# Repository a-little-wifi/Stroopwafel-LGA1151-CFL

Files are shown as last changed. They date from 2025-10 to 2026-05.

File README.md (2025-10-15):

# Stroopwafel LGA1151 Intel Coffee Lake motherboard

Trying to see how far I can get with implementing a modern-ish Intel platform in KiCad using public documentation and leaked schematics.

Here's some work in progress pictures (random layout (or ATX standard successor??? 👀)):

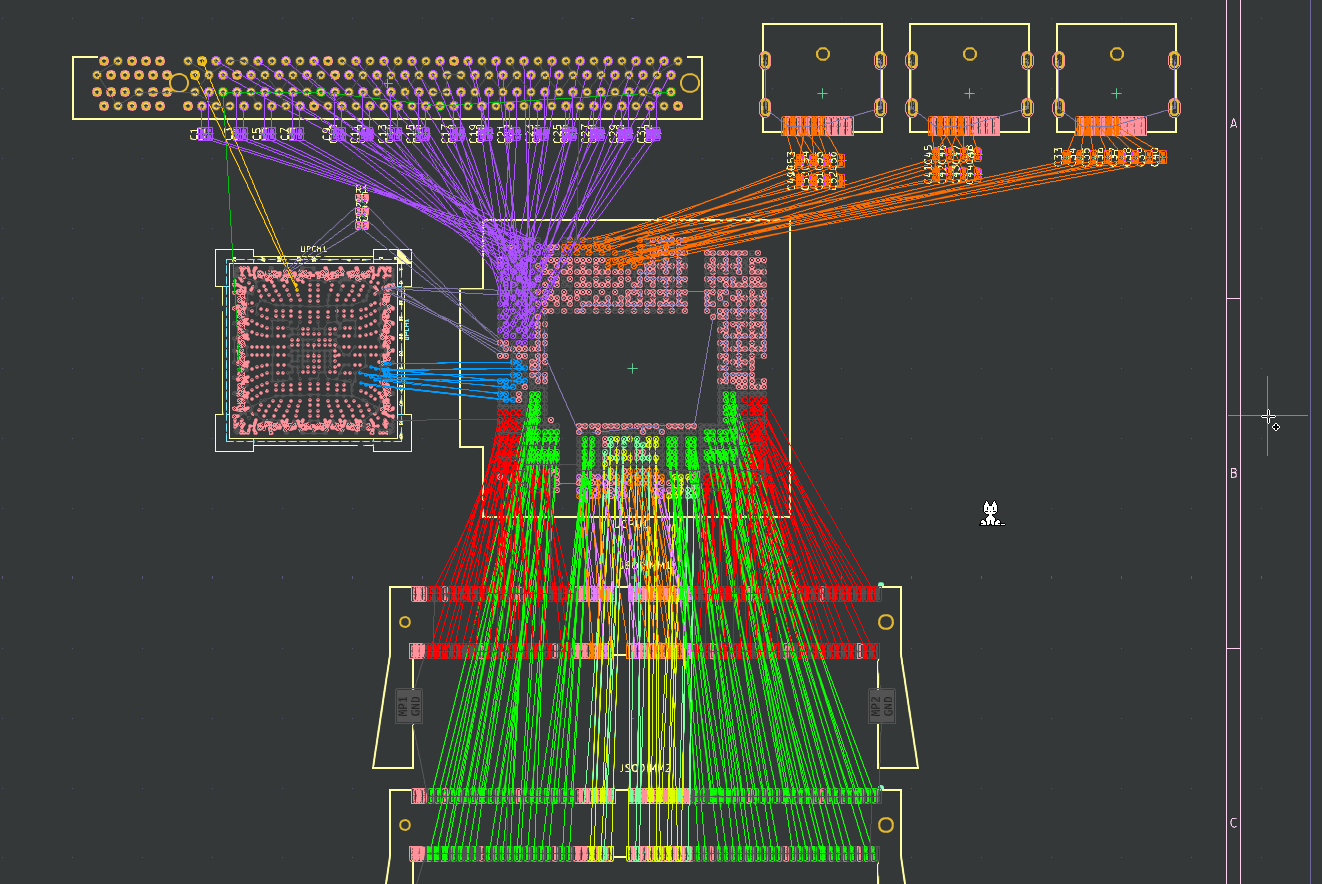
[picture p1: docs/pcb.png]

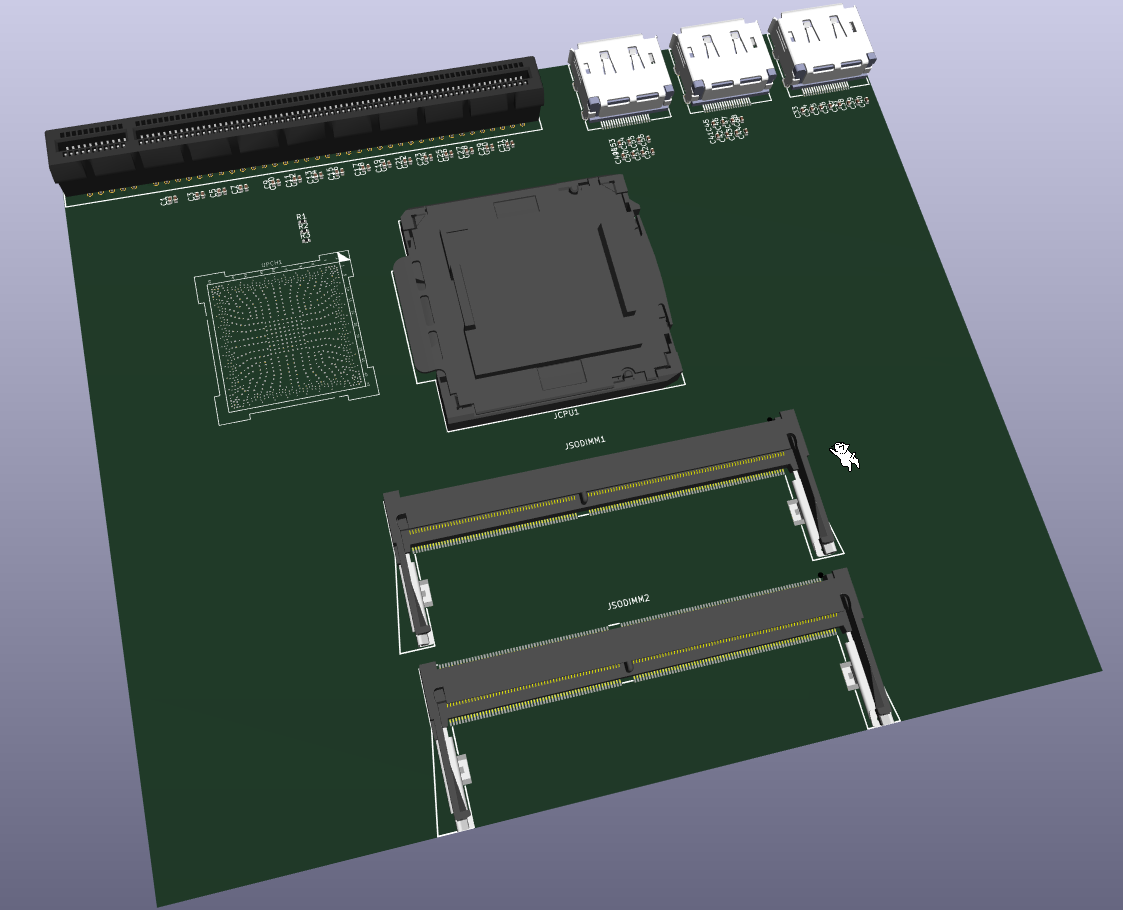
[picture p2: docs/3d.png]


Inspired by LCSC carrying LGA1151 sockets: https://www.lcsc.com/product-detail/C2761532.html (thanks for the footprint)

Thanks @mothenjoyer69 for extracting the PCH footprint from a random laptop boardview (LA-F711P)

CPU and PCH schematic symbols fully copied (and partially corrected) from pdf schematics by hand (took like 3 days...)

It's called Stroopwafel because I was eating a stroopwafel when I was trying to come up with a name. Also stroopwafels are supposed to go with coffee and it's Coffee Lake... get it?....

Mostly using LCFC NM-B551 (Lenovo Tiny5) and Wistron 17557-1 Copperbox (Acer N4660G my beloved) schematics for reference atm

The PCH footprint and symbol in this project should be applicable to (most of) Intel's 300 and 400 series chipsets. 300 series goes with 8th/9th gen and 400 series goes with 10th/11th gen.  
I'll be using a 300-series chipset for this project (probably Z390), since I'm using LGA1151. For 400 series you need LGA1200.

The goal is to create an easy to understand board and schematic layout that breaks out as much of the platform capabilities as possible.

Might build a laptop with a desktop CPU for fun later.

Am I insane? maybe. But I don't really see why I shouldn't try at the moment. It's a fun experiment at least.

No idea what board layout I'll use yet, but I don't feel like using a standard ATX formfactor, there's already plenty of boards like that. I kinda wanna make the PCH and CPU sections modular but I'll have to see about the practicalities of that.

I don't know how I'm gonna handle the EC and firmware yet, probably just gonna yoink it from an existing board and pray that it works without too much modification. I'm open to help regarding this. Maybe coreboot/libreboot?

Routing DDR4 will be fun.

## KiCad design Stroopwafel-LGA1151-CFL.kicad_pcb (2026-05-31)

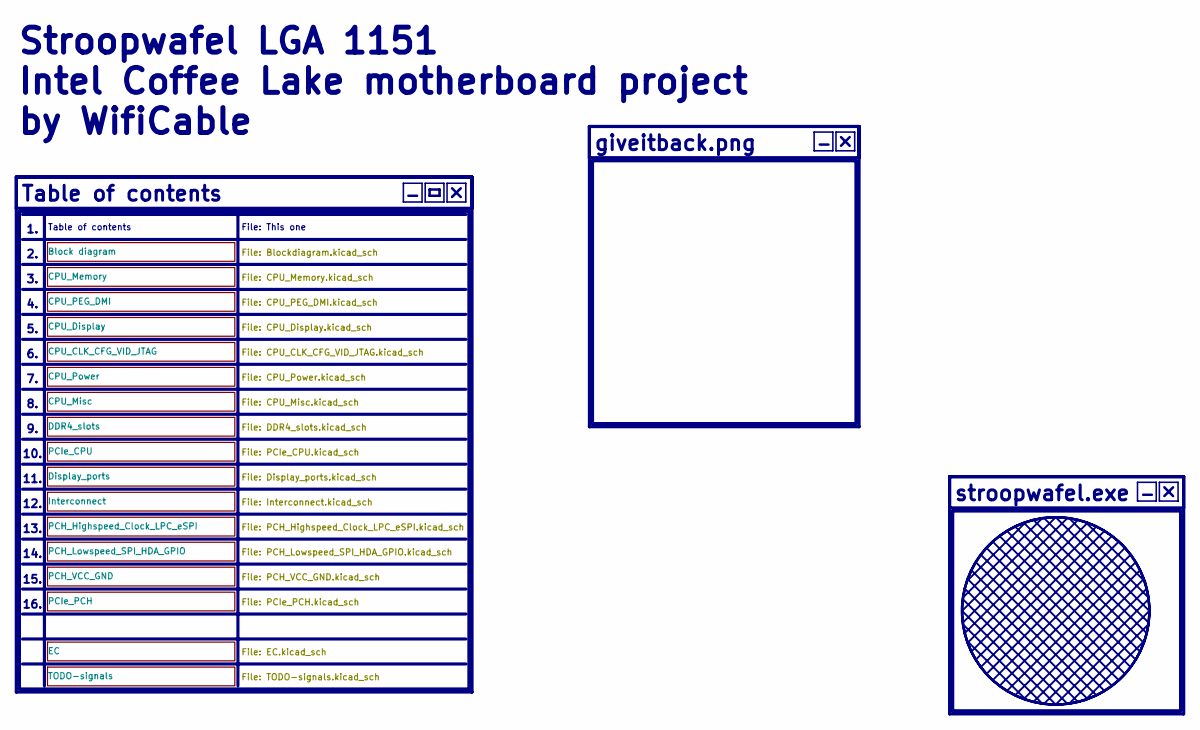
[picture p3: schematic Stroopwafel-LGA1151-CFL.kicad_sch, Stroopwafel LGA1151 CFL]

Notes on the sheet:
Stroopwafel LGA 1151 Intel Coffee Lake motherboard project by WifiCable
Table of contents
stroopwafel.exe
11.
15.
File: This one
giveitback.png
14.
16.
13.
10.
12.

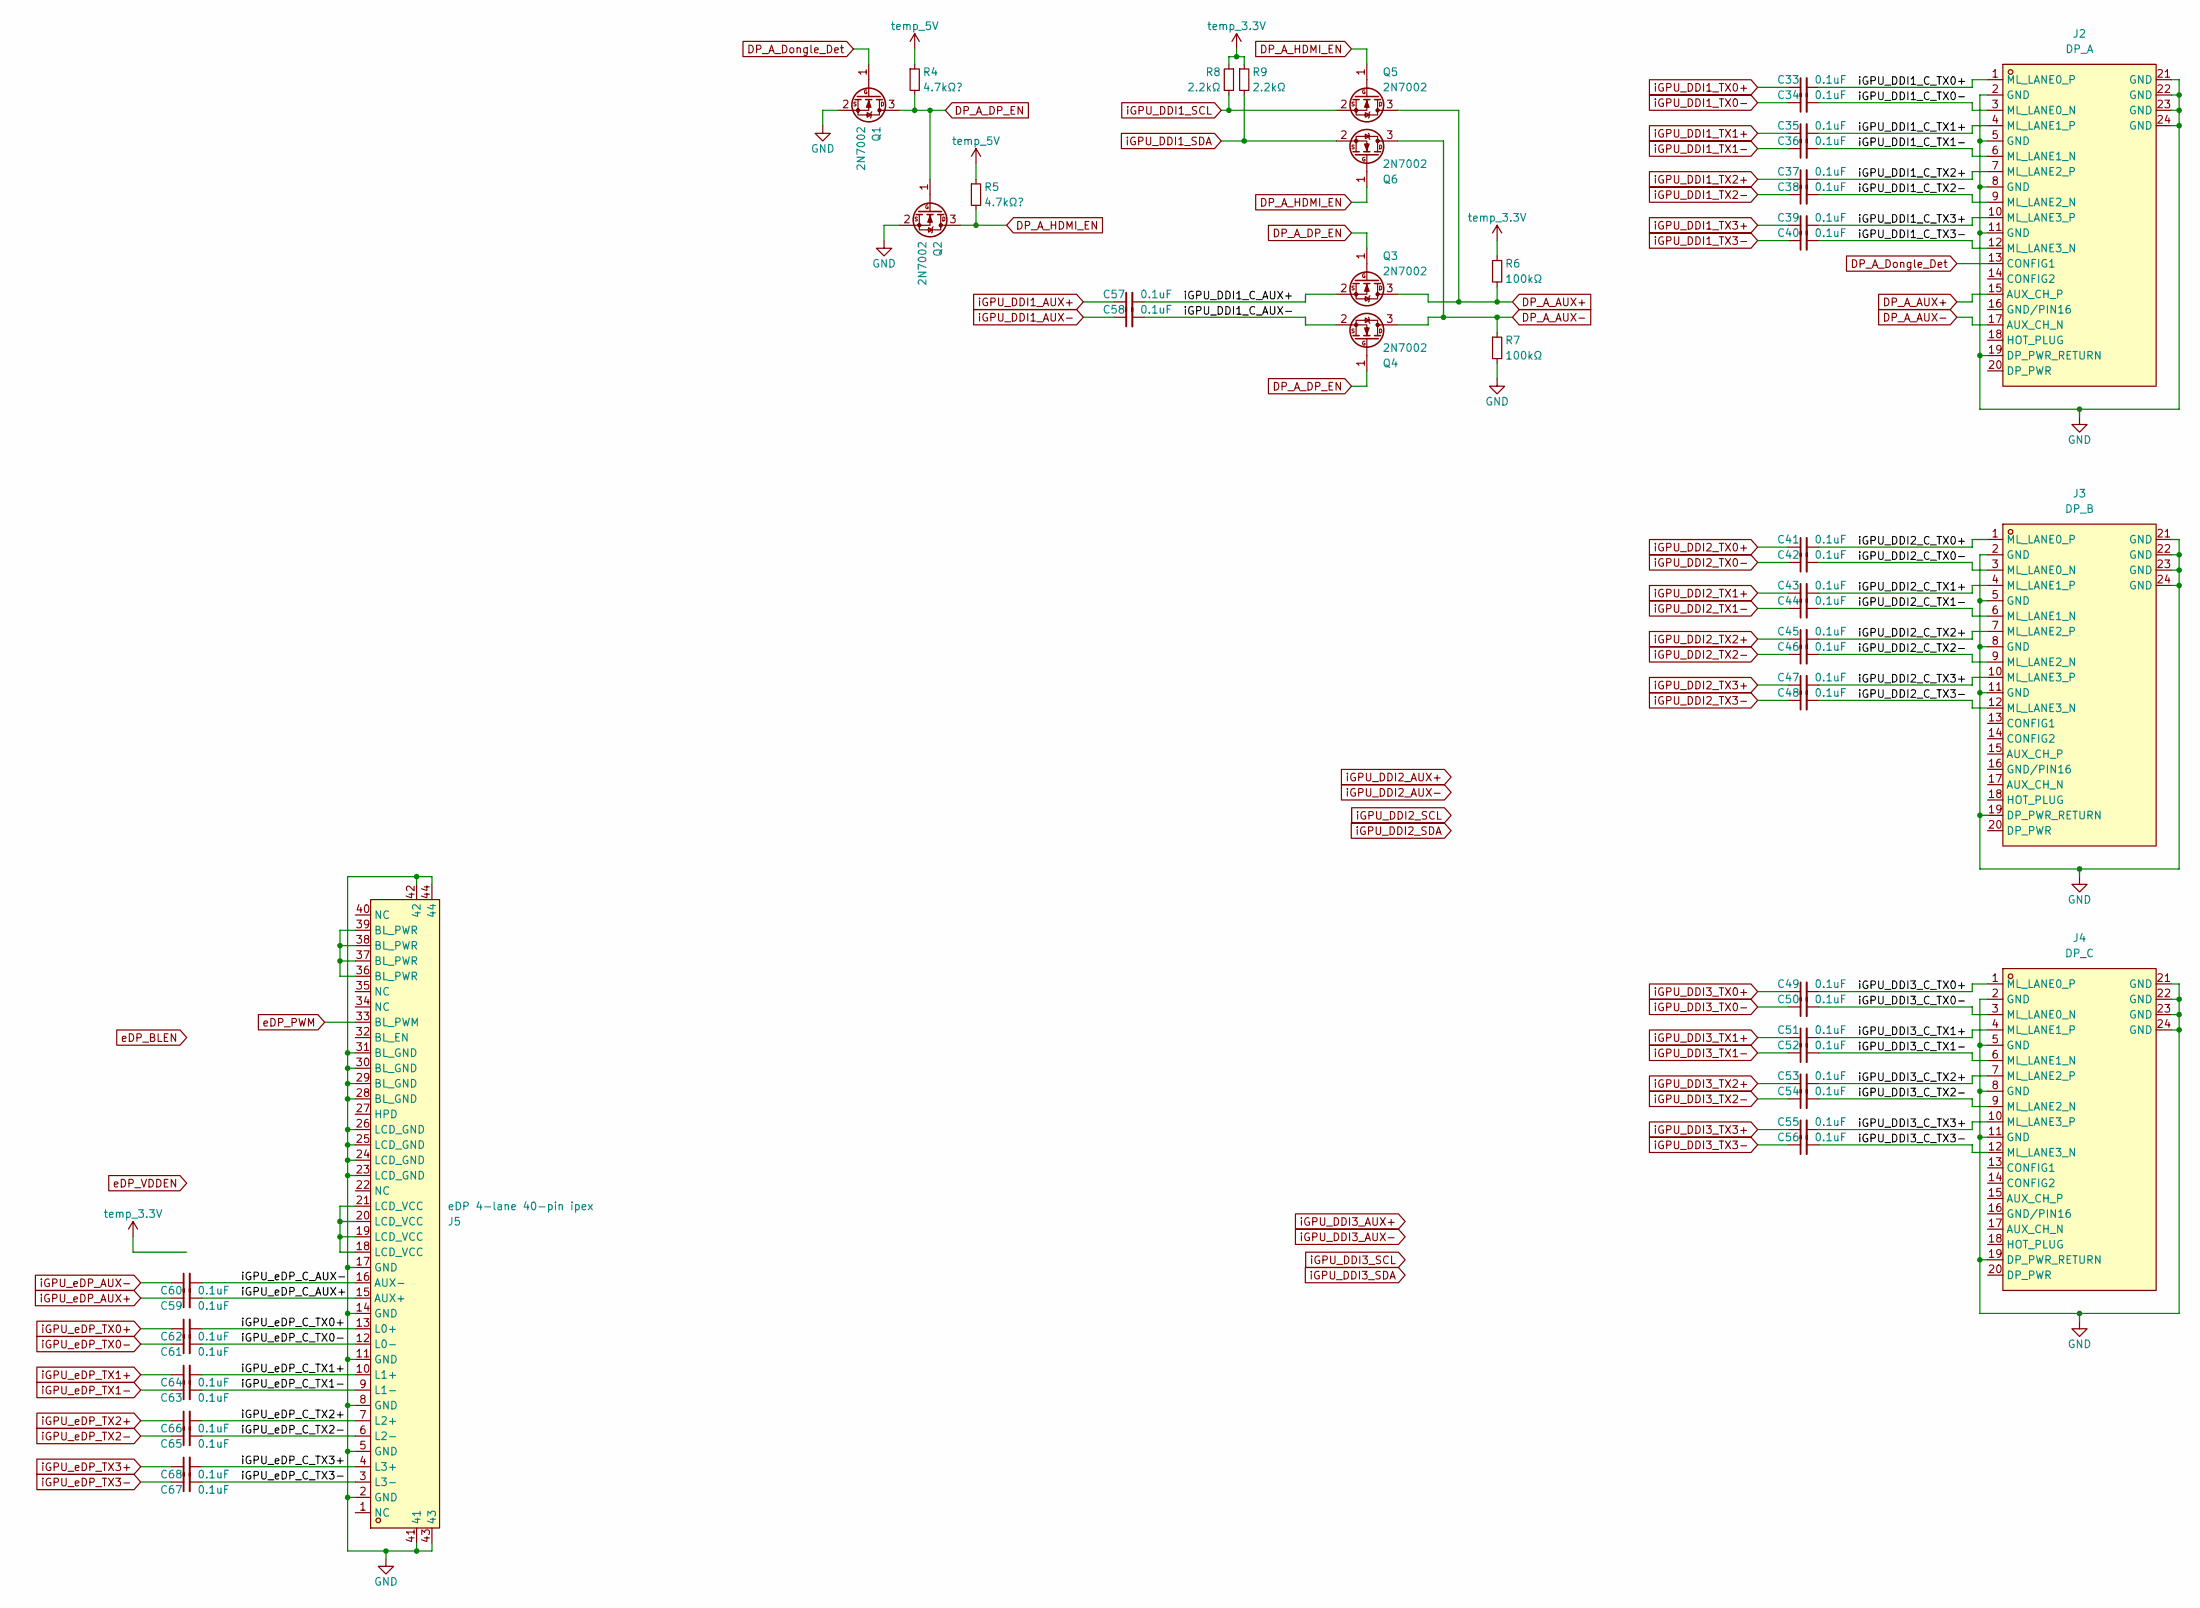
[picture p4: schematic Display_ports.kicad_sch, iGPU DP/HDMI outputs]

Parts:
C33, C34, C35, C36, C37, C38, C39, C40, C41, C42, C43, C44, C45, C46, C47, C48, C49, C50, C51, C52, C53, C54, C55, C56, C57, C58, C59, C60, C61, C62, C63, C64, C65, C66, C67, C68: 0.1uF; C_0402_1005Metric
J2: DP_A; DP-SMD_HYC16-DP20-178; LCSC Part C711350
J3: DP_B; DP-SMD_HYC16-DP20-178; LCSC Part C711350
J4: DP_C; DP-SMD_HYC16-DP20-178; LCSC Part C711350
J5: eDP 4-lane 40-pin ipex; 40pIPEX_20455-040E-76
Q1, Q2, Q3, Q4, Q5, Q6: 2N7002; SOT-23
R4, R5: 4.7kΩ?; R_0402_1005Metric
R6, R7: 100kΩ; R_0402_1005Metric
R8, R9: 2.2kΩ; R_0402_1005Metric

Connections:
/Display_ports/iGPU_DDI1_C_AUX+: C57.2, Q3.2 (S)
/Display_ports/iGPU_DDI1_C_AUX-: C58.2, Q4.2 (S)
/Display_ports/iGPU_DDI1_C_TX0+: C33.2, J2.1 (ML_LANE0_P)
/Display_ports/iGPU_DDI1_C_TX0-: C34.2, J2.3 (ML_LANE0_N)
/Display_ports/iGPU_DDI1_C_TX1+: C35.2, J2.4 (ML_LANE1_P)
/Display_ports/iGPU_DDI1_C_TX1-: C36.2, J2.6 (ML_LANE1_N)
/Display_ports/iGPU_DDI1_C_TX2+: C37.2, J2.7 (ML_LANE2_P)
/Display_ports/iGPU_DDI1_C_TX2-: C38.2, J2.9 (ML_LANE2_N)
/Display_ports/iGPU_DDI1_C_TX3+: C39.2, J2.10 (ML_LANE3_P)
/Display_ports/iGPU_DDI1_C_TX3-: C40.2, J2.12 (ML_LANE3_N)
/Display_ports/iGPU_DDI2_C_TX0+: C41.2, J3.1 (ML_LANE0_P)
/Display_ports/iGPU_DDI2_C_TX0-: C42.2, J3.3 (ML_LANE0_N)
/Display_ports/iGPU_DDI2_C_TX1+: C43.2, J3.4 (ML_LANE1_P)
/Display_ports/iGPU_DDI2_C_TX1-: C44.2, J3.6 (ML_LANE1_N)
/Display_ports/iGPU_DDI2_C_TX2+: C45.2, J3.7 (ML_LANE2_P)
/Display_ports/iGPU_DDI2_C_TX2-: C46.2, J3.9 (ML_LANE2_N)
/Display_ports/iGPU_DDI2_C_TX3+: C47.2, J3.10 (ML_LANE3_P)
/Display_ports/iGPU_DDI2_C_TX3-: C48.2, J3.12 (ML_LANE3_N)
/Display_ports/iGPU_DDI3_C_TX0+: C49.2, J4.1 (ML_LANE0_P)
/Display_ports/iGPU_DDI3_C_TX0-: C50.2, J4.3 (ML_LANE0_N)
/Display_ports/iGPU_DDI3_C_TX1+: C51.2, J4.4 (ML_LANE1_P)
/Display_ports/iGPU_DDI3_C_TX1-: C52.2, J4.6 (ML_LANE1_N)
/Display_ports/iGPU_DDI3_C_TX2+: C53.2, J4.7 (ML_LANE2_P)
/Display_ports/iGPU_DDI3_C_TX2-: C54.2, J4.9 (ML_LANE2_N)
/Display_ports/iGPU_DDI3_C_TX3+: C55.2, J4.10 (ML_LANE3_P)
/Display_ports/iGPU_DDI3_C_TX3-: C56.2, J4.12 (ML_LANE3_N)
/Display_ports/iGPU_eDP_C_AUX+: C59.2, J5.15 (AUX+)
/Display_ports/iGPU_eDP_C_AUX-: C60.2, J5.16 (AUX-)
/Display_ports/iGPU_eDP_C_TX0+: C62.2, J5.13 (L0+)
/Display_ports/iGPU_eDP_C_TX0-: C61.2, J5.12 (L0-)
/Display_ports/iGPU_eDP_C_TX1+: C64.2, J5.10 (L1+)
/Display_ports/iGPU_eDP_C_TX1-: C63.2, J5.9 (L1-)
/Display_ports/iGPU_eDP_C_TX2+: C66.2, J5.7 (L2+)
/Display_ports/iGPU_eDP_C_TX2-: C65.2, J5.6 (L2-)
/Display_ports/iGPU_eDP_C_TX3+: C68.2, J5.4 (L3+)
/Display_ports/iGPU_eDP_C_TX3-: C67.2, J5.3 (L3-)
DP_A_AUX+: J2.15 (AUX_CH_P), Q3.3 (D), Q5.3 (D), R6.2
DP_A_AUX-: J2.17 (AUX_CH_N), Q4.3 (D), Q6.3 (D), R7.1
DP_A_DP_EN: Q1.3 (D), Q2.1 (G), Q3.1 (G), Q4.1 (G), R4.2
DP_A_Dongle_Det: J2.13 (CONFIG1), Q1.1 (G)
DP_A_HDMI_EN: Q2.3 (D), Q5.1 (G), Q6.1 (G), R5.2
GND: J2.2 (GND), J2.5 (GND), J2.8 (GND), J2.11 (GND), J2.19 (DP_PWR_RETURN), J2.21 (GND), J2.22 (GND), J2.23 (GND), J2.24 (GND), J3.2 (GND), J3.5 (GND), J3.8 (GND), J3.11 (GND), J3.19 (DP_PWR_RETURN), J3.21 (GND), J3.22 (GND), J3.23 (GND), J3.24 (GND), J4.2 (GND), J4.5 (GND), J4.8 (GND), J4.11 (GND), J4.19 (DP_PWR_RETURN), J4.21 (GND), J4.22 (GND), J4.23 (GND), J4.24 (GND), J5.2 (GND), J5.5 (GND), J5.8 (GND), J5.11 (GND), J5.14 (GND), J5.17 (GND), J5.23 (LCD_GND), J5.24 (LCD_GND), J5.25 (LCD_GND), J5.26 (LCD_GND), J5.28 (BL_GND), J5.29 (BL_GND), J5.30 (BL_GND), J5.31 (BL_GND), J5.41, J5.42, J5.43, J5.44, Q1.2 (S), Q2.2 (S), R7.2; also elsewhere on the board
unnamed: J5.36 (BL_PWR), J5.37 (BL_PWR), J5.38 (BL_PWR), J5.39 (BL_PWR)
unnamed: J5.18 (LCD_VCC), J5.19 (LCD_VCC), J5.20 (LCD_VCC), J5.21 (LCD_VCC)
eDP_PWM: J5.33 (BL_PWM); also elsewhere on the board
iGPU_DDI1_AUX+: C57.1; also elsewhere on the board
iGPU_DDI1_AUX-: C58.1; also elsewhere on the board
iGPU_DDI1_SCL: Q5.2 (S), R8.2; also elsewhere on the board
iGPU_DDI1_SDA: Q6.2 (S), R9.2; also elsewhere on the board
iGPU_DDI1_TX0+: C33.1; also elsewhere on the board
iGPU_DDI1_TX0-: C34.1; also elsewhere on the board
iGPU_DDI1_TX1+: C35.1; also elsewhere on the board
iGPU_DDI1_TX1-: C36.1; also elsewhere on the board
iGPU_DDI1_TX2+: C37.1; also elsewhere on the board
iGPU_DDI1_TX2-: C38.1; also elsewhere on the board
iGPU_DDI1_TX3+: C39.1; also elsewhere on the board
iGPU_DDI1_TX3-: C40.1; also elsewhere on the board
iGPU_DDI2_TX0+: C41.1; also elsewhere on the board
iGPU_DDI2_TX0-: C42.1; also elsewhere on the board
iGPU_DDI2_TX1+: C43.1; also elsewhere on the board
iGPU_DDI2_TX1-: C44.1; also elsewhere on the board
iGPU_DDI2_TX2+: C45.1; also elsewhere on the board
iGPU_DDI2_TX2-: C46.1; also elsewhere on the board
iGPU_DDI2_TX3+: C47.1; also elsewhere on the board
iGPU_DDI2_TX3-: C48.1; also elsewhere on the board
iGPU_DDI3_TX0+: C49.1; also elsewhere on the board
iGPU_DDI3_TX0-: C50.1; also elsewhere on the board
iGPU_DDI3_TX1+: C51.1; also elsewhere on the board
iGPU_DDI3_TX1-: C52.1; also elsewhere on the board
iGPU_DDI3_TX2+: C53.1; also elsewhere on the board
iGPU_DDI3_TX2-: C54.1; also elsewhere on the board
iGPU_DDI3_TX3+: C55.1; also elsewhere on the board
iGPU_DDI3_TX3-: C56.1; also elsewhere on the board
iGPU_eDP_AUX+: C59.1; also elsewhere on the board
iGPU_eDP_AUX-: C60.1; also elsewhere on the board
iGPU_eDP_TX0+: C62.1; also elsewhere on the board
iGPU_eDP_TX0-: C61.1; also elsewhere on the board
iGPU_eDP_TX1+: C64.1; also elsewhere on the board
iGPU_eDP_TX1-: C63.1; also elsewhere on the board
iGPU_eDP_TX2+: C66.1; also elsewhere on the board
iGPU_eDP_TX2-: C65.1; also elsewhere on the board
iGPU_eDP_TX3+: C68.1; also elsewhere on the board
iGPU_eDP_TX3-: C67.1; also elsewhere on the board
temp_3.3V: R6.1, R8.1, R9.1; also elsewhere on the board
temp_5V: R4.1, R5.1

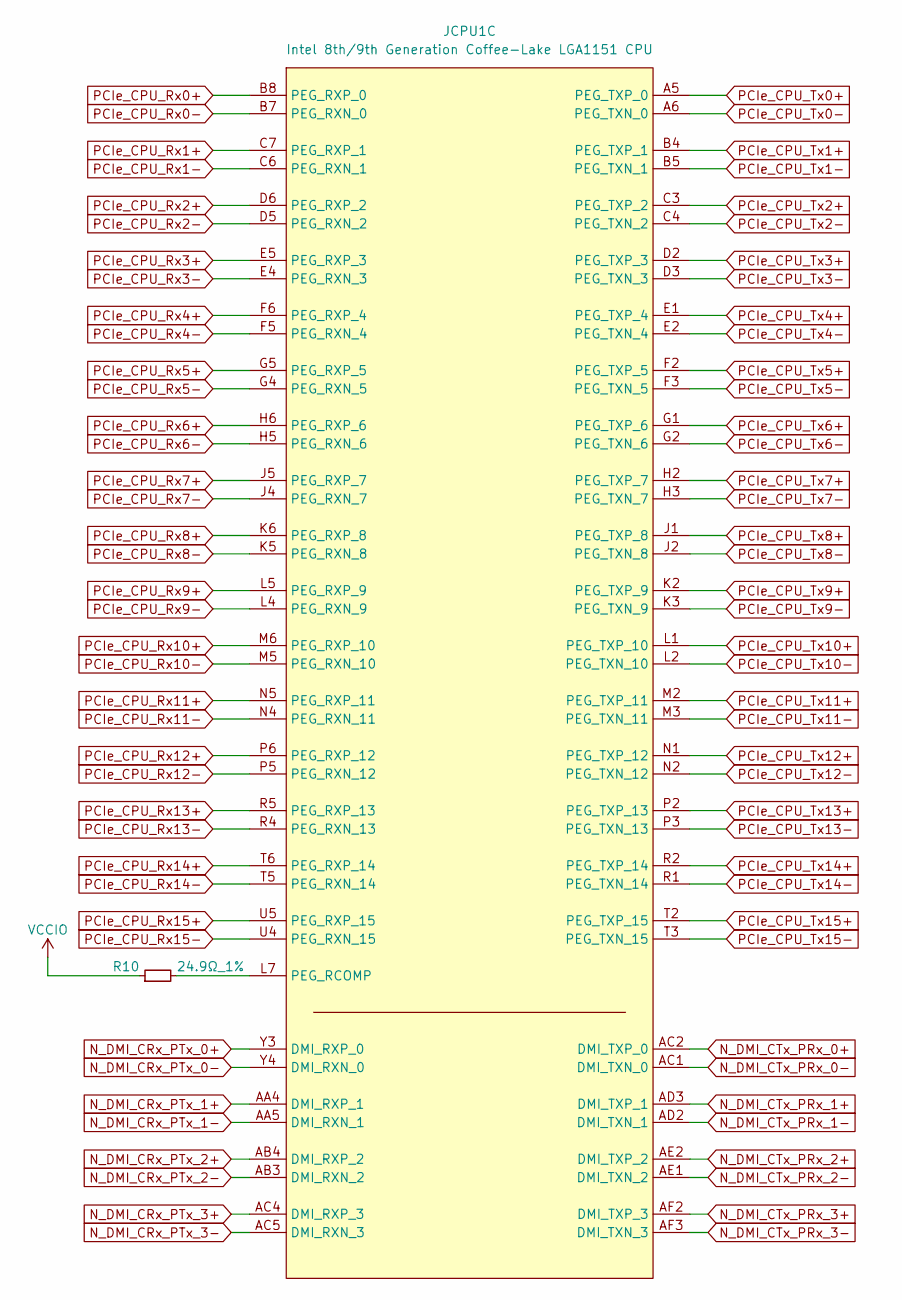
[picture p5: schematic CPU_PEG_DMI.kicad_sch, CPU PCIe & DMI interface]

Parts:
JCPU1: Intel 8th/9th Generation Coffee-Lake LGA1151 CPU; LGA-1151_L47.1-W42.5-P0.91_PE115127-4041-01H
R10: 24.9Ω_1%; R_0402_1005Metric

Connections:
N_DMI_CRx_PTx_0+: JCPU1.Y3 (DMI_RXP_0); also elsewhere on the board
N_DMI_CRx_PTx_0-: JCPU1.Y4 (DMI_RXN_0); also elsewhere on the board
N_DMI_CRx_PTx_1+: JCPU1.AA4 (DMI_RXP_1); also elsewhere on the board
N_DMI_CRx_PTx_1-: JCPU1.AA5 (DMI_RXN_1); also elsewhere on the board
N_DMI_CRx_PTx_2+: JCPU1.AB4 (DMI_RXP_2); also elsewhere on the board
N_DMI_CRx_PTx_2-: JCPU1.AB3 (DMI_RXN_2); also elsewhere on the board
N_DMI_CRx_PTx_3+: JCPU1.AC4 (DMI_RXP_3); also elsewhere on the board
N_DMI_CRx_PTx_3-: JCPU1.AC5 (DMI_RXN_3); also elsewhere on the board
N_DMI_CTx_PRx_0+: JCPU1.AC2 (DMI_TXP_0); also elsewhere on the board
N_DMI_CTx_PRx_0-: JCPU1.AC1 (DMI_TXN_0); also elsewhere on the board
N_DMI_CTx_PRx_1+: JCPU1.AD3 (DMI_TXP_1); also elsewhere on the board
N_DMI_CTx_PRx_1-: JCPU1.AD2 (DMI_TXN_1); also elsewhere on the board
N_DMI_CTx_PRx_2+: JCPU1.AE2 (DMI_TXP_2); also elsewhere on the board
N_DMI_CTx_PRx_2-: JCPU1.AE1 (DMI_TXN_2); also elsewhere on the board
N_DMI_CTx_PRx_3+: JCPU1.AF2 (DMI_TXP_3); also elsewhere on the board
N_DMI_CTx_PRx_3-: JCPU1.AF3 (DMI_TXN_3); also elsewhere on the board
unnamed: JCPU1.L7 (PEG_RCOMP), R10.2
PCIe_CPU_Rx0+: JCPU1.B8 (PEG_RXP_0); also elsewhere on the board
PCIe_CPU_Rx0-: JCPU1.B7 (PEG_RXN_0); also elsewhere on the board
PCIe_CPU_Rx1+: JCPU1.C7 (PEG_RXP_1); also elsewhere on the board
PCIe_CPU_Rx1-: JCPU1.C6 (PEG_RXN_1); also elsewhere on the board
PCIe_CPU_Rx2+: JCPU1.D6 (PEG_RXP_2); also elsewhere on the board
PCIe_CPU_Rx2-: JCPU1.D5 (PEG_RXN_2); also elsewhere on the board
PCIe_CPU_Rx3+: JCPU1.E5 (PEG_RXP_3); also elsewhere on the board
PCIe_CPU_Rx3-: JCPU1.E4 (PEG_RXN_3); also elsewhere on the board
PCIe_CPU_Rx4+: JCPU1.F6 (PEG_RXP_4); also elsewhere on the board
PCIe_CPU_Rx4-: JCPU1.F5 (PEG_RXN_4); also elsewhere on the board
PCIe_CPU_Rx5+: JCPU1.G5 (PEG_RXP_5); also elsewhere on the board
PCIe_CPU_Rx5-: JCPU1.G4 (PEG_RXN_5); also elsewhere on the board
PCIe_CPU_Rx6+: JCPU1.H6 (PEG_RXP_6); also elsewhere on the board
PCIe_CPU_Rx6-: JCPU1.H5 (PEG_RXN_6); also elsewhere on the board
PCIe_CPU_Rx7+: JCPU1.J5 (PEG_RXP_7); also elsewhere on the board
PCIe_CPU_Rx7-: JCPU1.J4 (PEG_RXN_7); also elsewhere on the board
PCIe_CPU_Rx8+: JCPU1.K6 (PEG_RXP_8); also elsewhere on the board
PCIe_CPU_Rx8-: JCPU1.K5 (PEG_RXN_8); also elsewhere on the board
PCIe_CPU_Rx9+: JCPU1.L5 (PEG_RXP_9); also elsewhere on the board
PCIe_CPU_Rx9-: JCPU1.L4 (PEG_RXN_9); also elsewhere on the board
PCIe_CPU_Rx10+: JCPU1.M6 (PEG_RXP_10); also elsewhere on the board
PCIe_CPU_Rx10-: JCPU1.M5 (PEG_RXN_10); also elsewhere on the board
PCIe_CPU_Rx11+: JCPU1.N5 (PEG_RXP_11); also elsewhere on the board
PCIe_CPU_Rx11-: JCPU1.N4 (PEG_RXN_11); also elsewhere on the board
PCIe_CPU_Rx12+: JCPU1.P6 (PEG_RXP_12); also elsewhere on the board
PCIe_CPU_Rx12-: JCPU1.P5 (PEG_RXN_12); also elsewhere on the board
PCIe_CPU_Rx13+: JCPU1.R5 (PEG_RXP_13); also elsewhere on the board
PCIe_CPU_Rx13-: JCPU1.R4 (PEG_RXN_13); also elsewhere on the board
PCIe_CPU_Rx14+: JCPU1.T6 (PEG_RXP_14); also elsewhere on the board
PCIe_CPU_Rx14-: JCPU1.T5 (PEG_RXN_14); also elsewhere on the board
PCIe_CPU_Rx15+: JCPU1.U5 (PEG_RXP_15); also elsewhere on the board
PCIe_CPU_Rx15-: JCPU1.U4 (PEG_RXN_15); also elsewhere on the board
PCIe_CPU_Tx0+: JCPU1.A5 (PEG_TXP_0); also elsewhere on the board
PCIe_CPU_Tx0-: JCPU1.A6 (PEG_TXN_0); also elsewhere on the board
PCIe_CPU_Tx1+: JCPU1.B4 (PEG_TXP_1); also elsewhere on the board
PCIe_CPU_Tx1-: JCPU1.B5 (PEG_TXN_1); also elsewhere on the board
PCIe_CPU_Tx2+: JCPU1.C3 (PEG_TXP_2); also elsewhere on the board
PCIe_CPU_Tx2-: JCPU1.C4 (PEG_TXN_2); also elsewhere on the board
PCIe_CPU_Tx3+: JCPU1.D2 (PEG_TXP_3); also elsewhere on the board
PCIe_CPU_Tx3-: JCPU1.D3 (PEG_TXN_3); also elsewhere on the board
PCIe_CPU_Tx4+: JCPU1.E1 (PEG_TXP_4); also elsewhere on the board
PCIe_CPU_Tx4-: JCPU1.E2 (PEG_TXN_4); also elsewhere on the board
PCIe_CPU_Tx5+: JCPU1.F2 (PEG_TXP_5); also elsewhere on the board
PCIe_CPU_Tx5-: JCPU1.F3 (PEG_TXN_5); also elsewhere on the board
PCIe_CPU_Tx6+: JCPU1.G1 (PEG_TXP_6); also elsewhere on the board
PCIe_CPU_Tx6-: JCPU1.G2 (PEG_TXN_6); also elsewhere on the board
PCIe_CPU_Tx7+: JCPU1.H2 (PEG_TXP_7); also elsewhere on the board
PCIe_CPU_Tx7-: JCPU1.H3 (PEG_TXN_7); also elsewhere on the board
PCIe_CPU_Tx8+: JCPU1.J1 (PEG_TXP_8); also elsewhere on the board
PCIe_CPU_Tx8-: JCPU1.J2 (PEG_TXN_8); also elsewhere on the board
PCIe_CPU_Tx9+: JCPU1.K2 (PEG_TXP_9); also elsewhere on the board
PCIe_CPU_Tx9-: JCPU1.K3 (PEG_TXN_9); also elsewhere on the board
PCIe_CPU_Tx10+: JCPU1.L1 (PEG_TXP_10); also elsewhere on the board
PCIe_CPU_Tx10-: JCPU1.L2 (PEG_TXN_10); also elsewhere on the board
PCIe_CPU_Tx11+: JCPU1.M2 (PEG_TXP_11); also elsewhere on the board
PCIe_CPU_Tx11-: JCPU1.M3 (PEG_TXN_11); also elsewhere on the board
PCIe_CPU_Tx12+: JCPU1.N1 (PEG_TXP_12); also elsewhere on the board
PCIe_CPU_Tx12-: JCPU1.N2 (PEG_TXN_12); also elsewhere on the board
PCIe_CPU_Tx13+: JCPU1.P2 (PEG_TXP_13); also elsewhere on the board
PCIe_CPU_Tx13-: JCPU1.P3 (PEG_TXN_13); also elsewhere on the board
PCIe_CPU_Tx14+: JCPU1.R2 (PEG_TXP_14); also elsewhere on the board
PCIe_CPU_Tx14-: JCPU1.R1 (PEG_TXN_14); also elsewhere on the board
PCIe_CPU_Tx15+: JCPU1.T2 (PEG_TXP_15); also elsewhere on the board
PCIe_CPU_Tx15-: JCPU1.T3 (PEG_TXN_15); also elsewhere on the board
VCCIO: R10.1; also elsewhere on the board

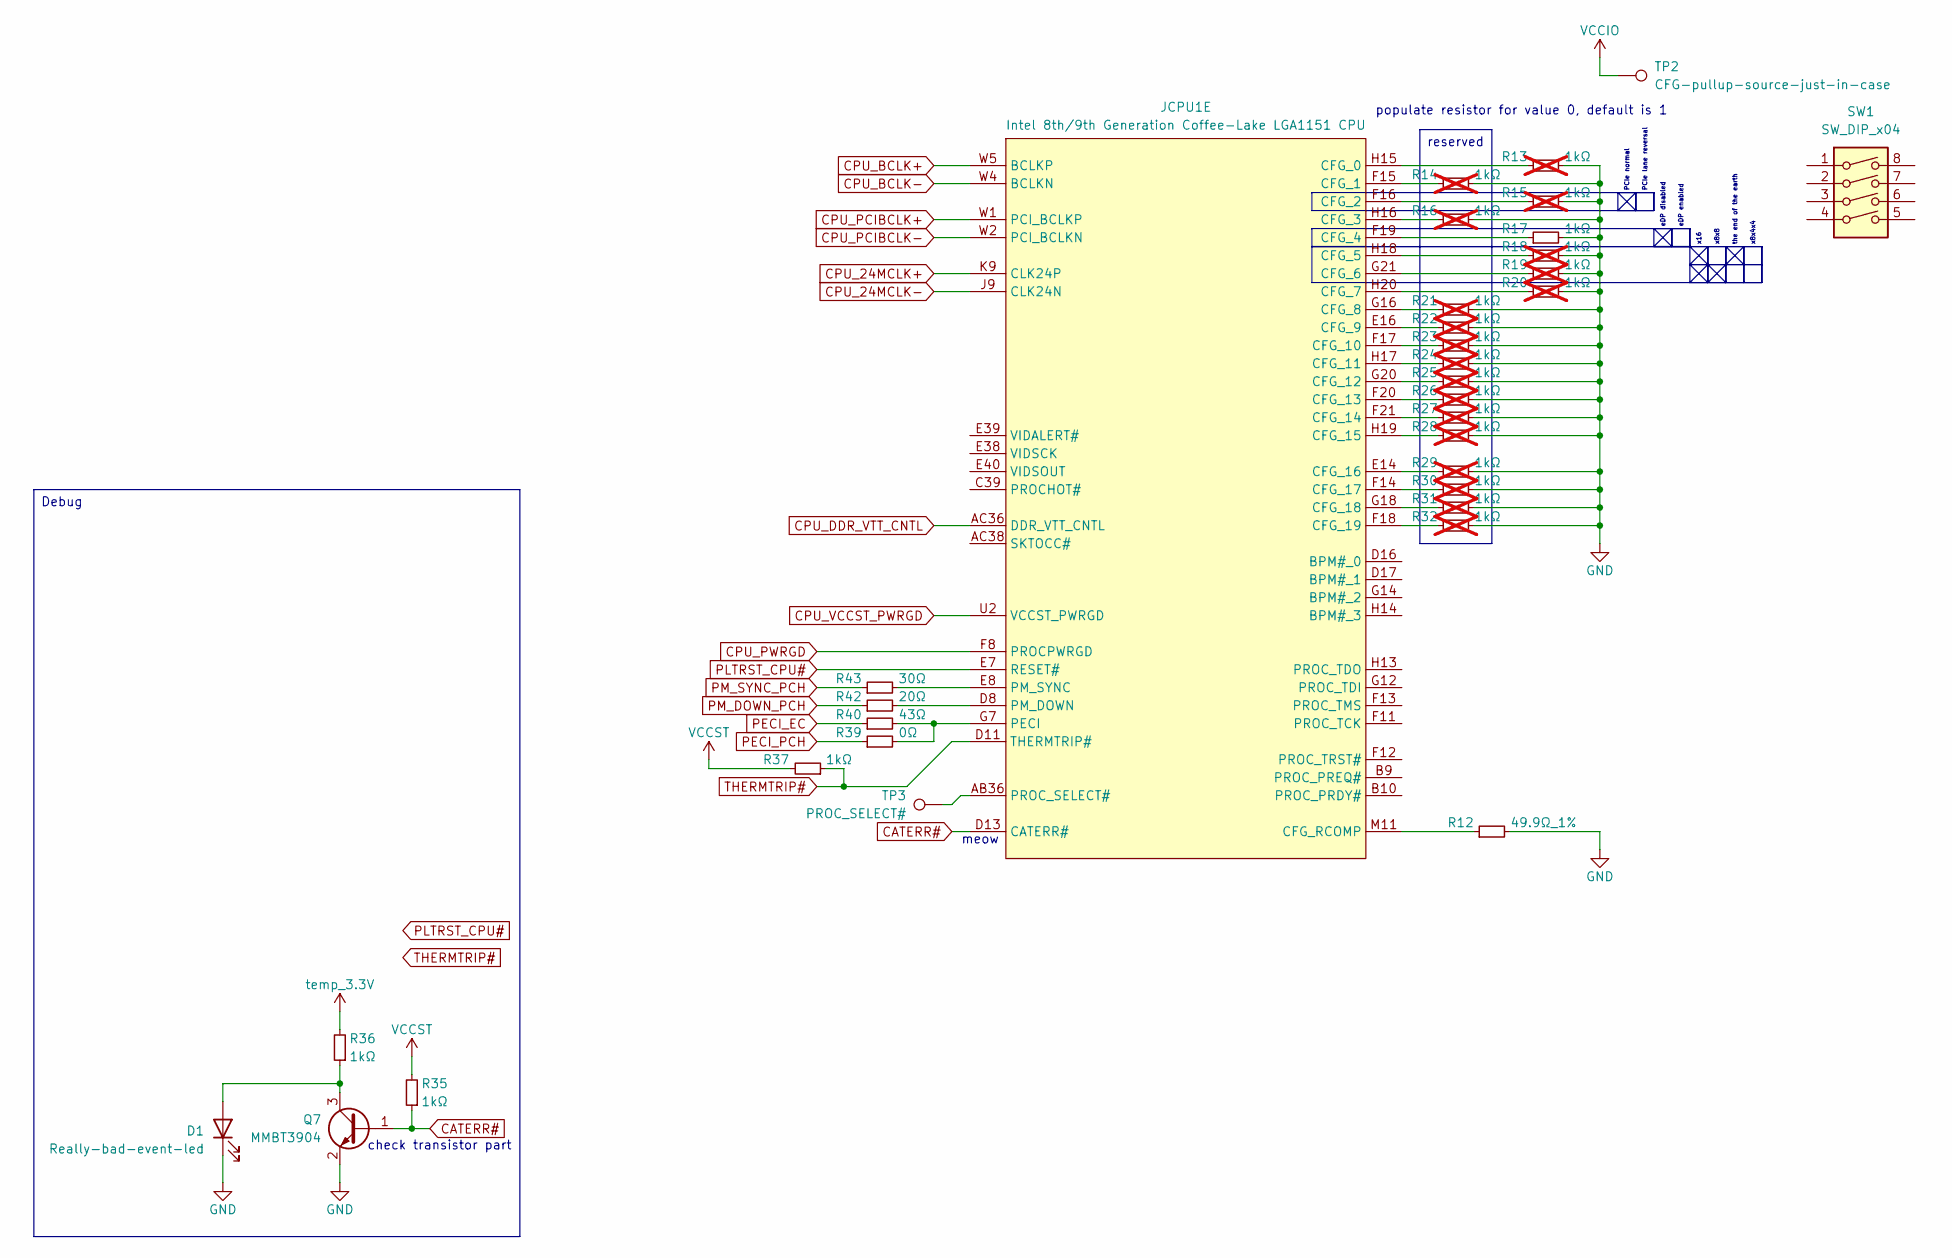
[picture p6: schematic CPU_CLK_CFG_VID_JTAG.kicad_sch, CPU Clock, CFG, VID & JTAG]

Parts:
D1: Really-bad-event-led; LED_0603_1608Metric
JCPU1: Intel 8th/9th Generation Coffee-Lake LGA1151 CPU; LGA-1151_L47.1-W42.5-P0.91_PE115127-4041-01H
Q7: MMBT3904; SOT-23
R12: 49.9Ω_1%; R_0402_1005Metric
R13, R14, R15, R16, R18, R19, R20, R21, R22, R23, R24, R25, R26, R27, R28, R29, R30, R31, R32: 1kΩ; R_0402_1005Metric; not fitted
R17, R35, R36, R37: 1kΩ; R_0402_1005Metric
R39: 0Ω; R_0402_1005Metric
R40: 43Ω; R_0402_1005Metric
R42: 20Ω; R_0402_1005Metric
R43: 30Ω; R_0402_1005Metric
SW1: SW_DIP_x04
TP2: CFG-pullup-source-just-in-case; TestPoint_Pad_D2.0mm
TP3: PROC_SELECT#; TestPoint_Pad_D2.0mm

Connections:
CATERR#: JCPU1.D13 (CATERR#), Q7.1 (B), R35.1
CPU_24MCLK+: JCPU1.K9 (CLK24P); also elsewhere on the board
CPU_24MCLK-: JCPU1.J9 (CLK24N); also elsewhere on the board
CPU_BCLK+: JCPU1.W5 (BCLKP); also elsewhere on the board
CPU_BCLK-: JCPU1.W4 (BCLKN); also elsewhere on the board
CPU_DDR_VTT_CNTL: JCPU1.AC36 (DDR_VTT_CNTL)
CPU_PCIBCLK+: JCPU1.W1 (PCI_BCLKP); also elsewhere on the board
CPU_PCIBCLK-: JCPU1.W2 (PCI_BCLKN); also elsewhere on the board
CPU_PWRGD: JCPU1.F8 (PROCPWRGD); also elsewhere on the board
CPU_VCCST_PWRGD: JCPU1.U2 (VCCST_PWRGD)
GND: D1.1 (K), Q7.2 (E), R12.2, R13.2, R14.2, R15.2, R16.2, R17.2, R18.2, R19.2, R20.2, R21.2, R22.2, R23.2, R24.2, R25.2, R26.2, R27.2, R28.2, R29.2, R30.2, R31.2, R32.2; also elsewhere on the board
unnamed: D1.2 (A), Q7.3 (C), R36.1
unnamed: JCPU1.H15 (CFG_0), R13.1
unnamed: JCPU1.F15 (CFG_1), R14.1
unnamed: JCPU1.F16 (CFG_2), R15.1
unnamed: JCPU1.H16 (CFG_3), R16.1
unnamed: JCPU1.F19 (CFG_4), R17.1
unnamed: JCPU1.H18 (CFG_5), R18.1
unnamed: JCPU1.G21 (CFG_6), R19.1
unnamed: JCPU1.H20 (CFG_7), R20.1
unnamed: JCPU1.G16 (CFG_8), R21.1
unnamed: JCPU1.E16 (CFG_9), R22.1
unnamed: JCPU1.F17 (CFG_10), R23.1
unnamed: JCPU1.H17 (CFG_11), R24.1
unnamed: JCPU1.G20 (CFG_12), R25.1
unnamed: JCPU1.F20 (CFG_13), R26.1
unnamed: JCPU1.F21 (CFG_14), R27.1
unnamed: JCPU1.H19 (CFG_15), R28.1
unnamed: JCPU1.E14 (CFG_16), R29.1
unnamed: JCPU1.F14 (CFG_17), R30.1
unnamed: JCPU1.G18 (CFG_18), R31.1
unnamed: JCPU1.F18 (CFG_19), R32.1
unnamed: JCPU1.M11 (CFG_RCOMP), R12.1
unnamed: JCPU1.G7 (PECI), R39.2, R40.2
unnamed: JCPU1.D8 (PM_DOWN), R42.2
unnamed: JCPU1.E8 (PM_SYNC), R43.2
unnamed: JCPU1.AB36 (PROC_SELECT#), TP3.1
PECI_EC: R40.1
PECI_PCH: R39.1; also elsewhere on the board
PLTRST_CPU#: JCPU1.E7 (RESET#); also elsewhere on the board
PM_DOWN_PCH: R42.1; also elsewhere on the board
PM_SYNC_PCH: R43.1; also elsewhere on the board
THERMTRIP#: JCPU1.D11 (THERMTRIP#), R37.1; also elsewhere on the board
VCCIO: TP2.1; also elsewhere on the board
VCCST: R35.2, R37.2; also elsewhere on the board
temp_3.3V: R36.2; also elsewhere on the board

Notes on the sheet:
PCIe lane reversal
eDP disabled
x8x4x4
x16
x8x8
check transistor part
eDP enabled
PCIe normal
the end of the earth
meow
populate resistor for value 0, default is 1
reserved
Debug

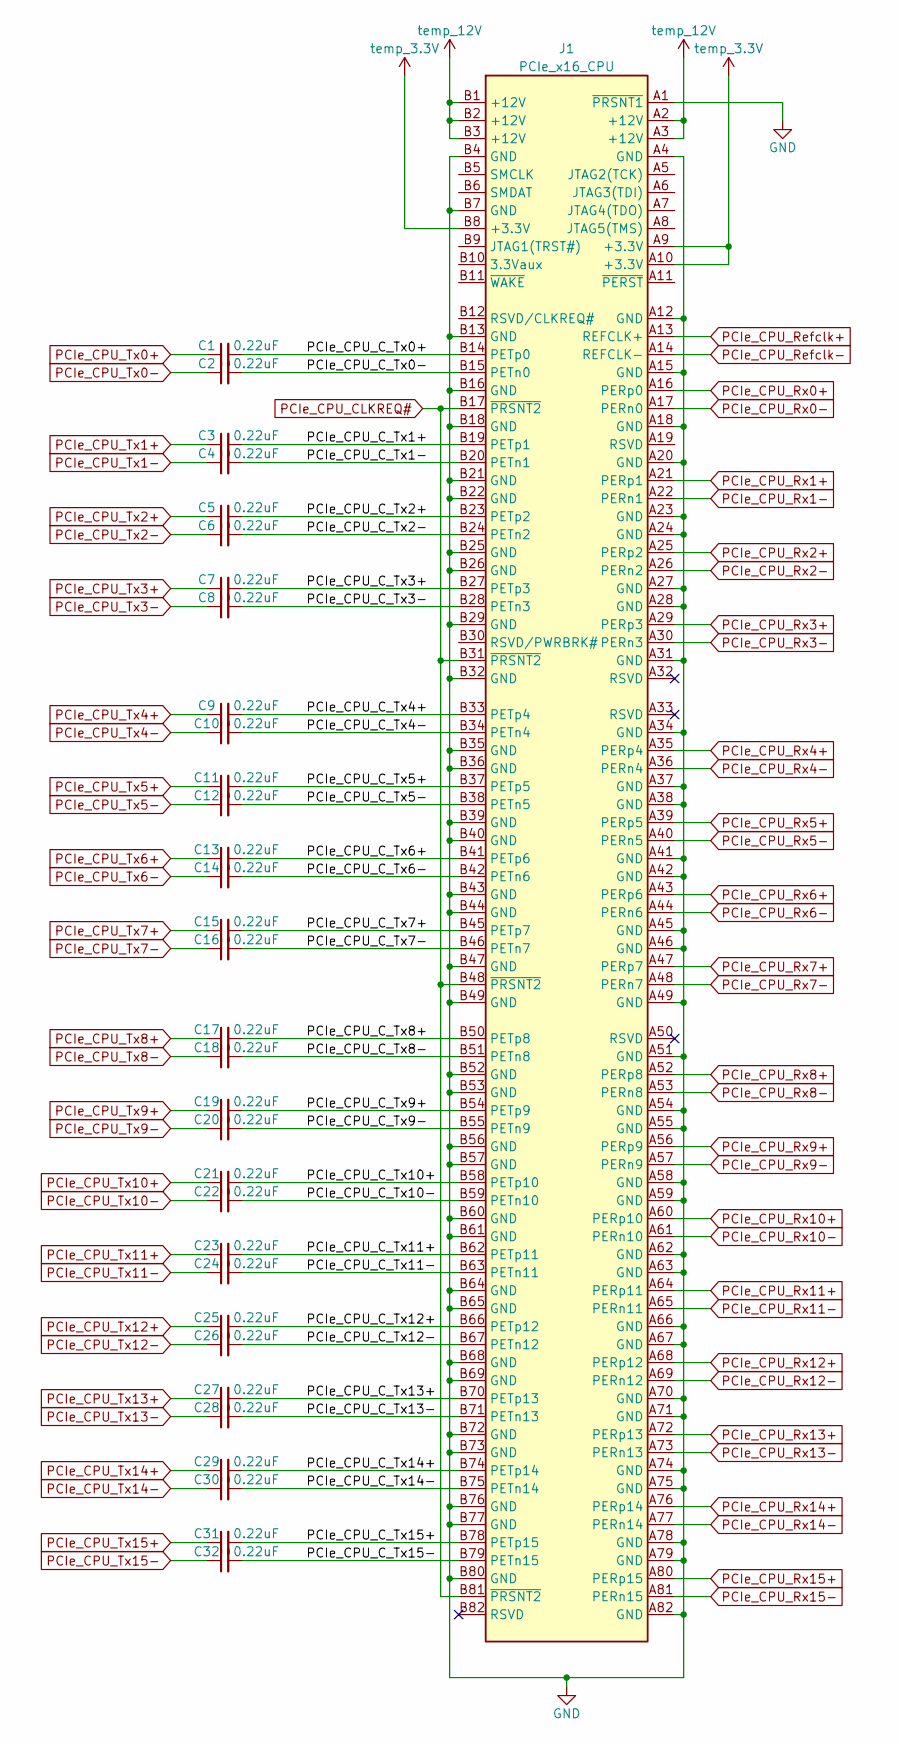
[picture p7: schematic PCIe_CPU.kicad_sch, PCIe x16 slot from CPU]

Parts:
C1, C2, C3, C4, C5, C6, C7, C8, C9, C10, C11, C12, C13, C14, C15, C16, C17, C18, C19, C20, C21, C22, C23, C24, C25, C26, C27, C28, C29, C30, C31, C32: 0.22uF; C_0402_1005Metric
J1: PCIe_x16_CPU; PCIe_x16_tht_smallholes

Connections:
/PCIe_CPU/PCIe_CPU_C_Tx0+: C1.2, J1.B14 (PETp0)
/PCIe_CPU/PCIe_CPU_C_Tx0-: C2.2, J1.B15 (PETn0)
/PCIe_CPU/PCIe_CPU_C_Tx1+: C3.2, J1.B19 (PETp1)
/PCIe_CPU/PCIe_CPU_C_Tx1-: C4.2, J1.B20 (PETn1)
/PCIe_CPU/PCIe_CPU_C_Tx2+: C5.2, J1.B23 (PETp2)
/PCIe_CPU/PCIe_CPU_C_Tx2-: C6.2, J1.B24 (PETn2)
/PCIe_CPU/PCIe_CPU_C_Tx3+: C7.2, J1.B27 (PETp3)
/PCIe_CPU/PCIe_CPU_C_Tx3-: C8.2, J1.B28 (PETn3)
/PCIe_CPU/PCIe_CPU_C_Tx4+: C9.2, J1.B33 (PETp4)
/PCIe_CPU/PCIe_CPU_C_Tx4-: C10.2, J1.B34 (PETn4)
/PCIe_CPU/PCIe_CPU_C_Tx5+: C11.2, J1.B37 (PETp5)
/PCIe_CPU/PCIe_CPU_C_Tx5-: C12.2, J1.B38 (PETn5)
/PCIe_CPU/PCIe_CPU_C_Tx6+: C13.2, J1.B41 (PETp6)
/PCIe_CPU/PCIe_CPU_C_Tx6-: C14.2, J1.B42 (PETn6)
/PCIe_CPU/PCIe_CPU_C_Tx7+: C15.2, J1.B45 (PETp7)
/PCIe_CPU/PCIe_CPU_C_Tx7-: C16.2, J1.B46 (PETn7)
/PCIe_CPU/PCIe_CPU_C_Tx8+: C17.2, J1.B50 (PETp8)
/PCIe_CPU/PCIe_CPU_C_Tx8-: C18.2, J1.B51 (PETn8)
/PCIe_CPU/PCIe_CPU_C_Tx9+: C19.2, J1.B54 (PETp9)
/PCIe_CPU/PCIe_CPU_C_Tx9-: C20.2, J1.B55 (PETn9)
/PCIe_CPU/PCIe_CPU_C_Tx10+: C21.2, J1.B58 (PETp10)
/PCIe_CPU/PCIe_CPU_C_Tx10-: C22.2, J1.B59 (PETn10)
/PCIe_CPU/PCIe_CPU_C_Tx11+: C23.2, J1.B62 (PETp11)
/PCIe_CPU/PCIe_CPU_C_Tx11-: C24.2, J1.B63 (PETn11)
/PCIe_CPU/PCIe_CPU_C_Tx12+: C25.2, J1.B66 (PETp12)
/PCIe_CPU/PCIe_CPU_C_Tx12-: C26.2, J1.B67 (PETn12)
/PCIe_CPU/PCIe_CPU_C_Tx13+: C27.2, J1.B70 (PETp13)
/PCIe_CPU/PCIe_CPU_C_Tx13-: C28.2, J1.B71 (PETn13)
/PCIe_CPU/PCIe_CPU_C_Tx14+: C29.2, J1.B74 (PETp14)
/PCIe_CPU/PCIe_CPU_C_Tx14-: C30.2, J1.B75 (PETn14)
/PCIe_CPU/PCIe_CPU_C_Tx15+: C31.2, J1.B78 (PETp15)
/PCIe_CPU/PCIe_CPU_C_Tx15-: C32.2, J1.B79 (PETn15)
GND: J1.A1 (~PRSNT1), J1.A4 (GND), J1.A12 (GND), J1.A15 (GND), J1.A18 (GND), J1.A20 (GND), J1.A23 (GND), J1.A24 (GND), J1.A27 (GND), J1.A28 (GND), J1.A31 (GND), J1.A34 (GND), J1.A37 (GND), J1.A38 (GND), J1.A41 (GND), J1.A42 (GND), J1.A45 (GND), J1.A46 (GND), J1.A49 (GND), J1.A51 (GND), J1.A54 (GND), J1.A55 (GND), J1.A58 (GND), J1.A59 (GND), J1.A62 (GND), J1.A63 (GND), J1.A66 (GND), J1.A67 (GND), J1.A70 (GND), J1.A71 (GND), J1.A74 (GND), J1.A75 (GND), J1.A78 (GND), J1.A79 (GND), J1.A82 (GND), J1.B4 (GND), J1.B7 (GND), J1.B13 (GND), J1.B16 (GND), J1.B18 (GND), J1.B21 (GND), J1.B22 (GND), J1.B25 (GND), J1.B26 (GND), J1.B29 (GND), J1.B32 (GND), J1.B35 (GND), J1.B36 (GND), J1.B39 (GND), J1.B40 (GND), J1.B43 (GND), J1.B44 (GND), J1.B47 (GND), J1.B49 (GND), J1.B52 (GND), J1.B53 (GND), J1.B56 (GND), J1.B57 (GND), J1.B60 (GND), J1.B61 (GND), J1.B64 (GND), J1.B65 (GND), J1.B68 (GND), J1.B69 (GND), J1.B72 (GND), J1.B73 (GND), J1.B76 (GND), J1.B77 (GND), J1.B80 (GND); also elsewhere on the board
PCIe_CPU_CLKREQ#: J1.B17 (~PRSNT2), J1.B31 (~PRSNT2), J1.B48 (~PRSNT2), J1.B81 (~PRSNT2); also elsewhere on the board
PCIe_CPU_Refclk+: J1.A13 (REFCLK+); also elsewhere on the board
PCIe_CPU_Refclk-: J1.A14 (REFCLK-); also elsewhere on the board
PCIe_CPU_Rx0+: J1.A16 (PERp0); also elsewhere on the board
PCIe_CPU_Rx0-: J1.A17 (PERn0); also elsewhere on the board
PCIe_CPU_Rx1+: J1.A21 (PERp1); also elsewhere on the board
PCIe_CPU_Rx1-: J1.A22 (PERn1); also elsewhere on the board
PCIe_CPU_Rx2+: J1.A25 (PERp2); also elsewhere on the board
PCIe_CPU_Rx2-: J1.A26 (PERn2); also elsewhere on the board
PCIe_CPU_Rx3+: J1.A29 (PERp3); also elsewhere on the board
PCIe_CPU_Rx3-: J1.A30 (PERn3); also elsewhere on the board
PCIe_CPU_Rx4+: J1.A35 (PERp4); also elsewhere on the board
PCIe_CPU_Rx4-: J1.A36 (PERn4); also elsewhere on the board
PCIe_CPU_Rx5+: J1.A39 (PERp5); also elsewhere on the board
PCIe_CPU_Rx5-: J1.A40 (PERn5); also elsewhere on the board
PCIe_CPU_Rx6+: J1.A43 (PERp6); also elsewhere on the board
PCIe_CPU_Rx6-: J1.A44 (PERn6); also elsewhere on the board
PCIe_CPU_Rx7+: J1.A47 (PERp7); also elsewhere on the board
PCIe_CPU_Rx7-: J1.A48 (PERn7); also elsewhere on the board
PCIe_CPU_Rx8+: J1.A52 (PERp8); also elsewhere on the board
PCIe_CPU_Rx8-: J1.A53 (PERn8); also elsewhere on the board
PCIe_CPU_Rx9+: J1.A56 (PERp9); also elsewhere on the board
PCIe_CPU_Rx9-: J1.A57 (PERn9); also elsewhere on the board
PCIe_CPU_Rx10+: J1.A60 (PERp10); also elsewhere on the board
PCIe_CPU_Rx10-: J1.A61 (PERn10); also elsewhere on the board
PCIe_CPU_Rx11+: J1.A64 (PERp11); also elsewhere on the board
PCIe_CPU_Rx11-: J1.A65 (PERn11); also elsewhere on the board
PCIe_CPU_Rx12+: J1.A68 (PERp12); also elsewhere on the board
PCIe_CPU_Rx12-: J1.A69 (PERn12); also elsewhere on the board
PCIe_CPU_Rx13+: J1.A72 (PERp13); also elsewhere on the board
PCIe_CPU_Rx13-: J1.A73 (PERn13); also elsewhere on the board
PCIe_CPU_Rx14+: J1.A76 (PERp14); also elsewhere on the board
PCIe_CPU_Rx14-: J1.A77 (PERn14); also elsewhere on the board
PCIe_CPU_Rx15+: J1.A80 (PERp15); also elsewhere on the board
PCIe_CPU_Rx15-: J1.A81 (PERn15); also elsewhere on the board
PCIe_CPU_Tx0+: C1.1; also elsewhere on the board
PCIe_CPU_Tx0-: C2.1; also elsewhere on the board
PCIe_CPU_Tx1+: C3.1; also elsewhere on the board
PCIe_CPU_Tx1-: C4.1; also elsewhere on the board
PCIe_CPU_Tx2+: C5.1; also elsewhere on the board
PCIe_CPU_Tx2-: C6.1; also elsewhere on the board
PCIe_CPU_Tx3+: C7.1; also elsewhere on the board
PCIe_CPU_Tx3-: C8.1; also elsewhere on the board
PCIe_CPU_Tx4+: C9.1; also elsewhere on the board
PCIe_CPU_Tx4-: C10.1; also elsewhere on the board
PCIe_CPU_Tx5+: C11.1; also elsewhere on the board
PCIe_CPU_Tx5-: C12.1; also elsewhere on the board
PCIe_CPU_Tx6+: C13.1; also elsewhere on the board
PCIe_CPU_Tx6-: C14.1; also elsewhere on the board
PCIe_CPU_Tx7+: C15.1; also elsewhere on the board
PCIe_CPU_Tx7-: C16.1; also elsewhere on the board
PCIe_CPU_Tx8+: C17.1; also elsewhere on the board
PCIe_CPU_Tx8-: C18.1; also elsewhere on the board
PCIe_CPU_Tx9+: C19.1; also elsewhere on the board
PCIe_CPU_Tx9-: C20.1; also elsewhere on the board
PCIe_CPU_Tx10+: C21.1; also elsewhere on the board
PCIe_CPU_Tx10-: C22.1; also elsewhere on the board
PCIe_CPU_Tx11+: C23.1; also elsewhere on the board
PCIe_CPU_Tx11-: C24.1; also elsewhere on the board
PCIe_CPU_Tx12+: C25.1; also elsewhere on the board
PCIe_CPU_Tx12-: C26.1; also elsewhere on the board
PCIe_CPU_Tx13+: C27.1; also elsewhere on the board
PCIe_CPU_Tx13-: C28.1; also elsewhere on the board
PCIe_CPU_Tx14+: C29.1; also elsewhere on the board
PCIe_CPU_Tx14-: C30.1; also elsewhere on the board
PCIe_CPU_Tx15+: C31.1; also elsewhere on the board
PCIe_CPU_Tx15-: C32.1; also elsewhere on the board
temp_3.3V: J1.A9 (+3.3V), J1.A10 (+3.3V), J1.B8 (+3.3V); also elsewhere on the board
temp_12V: J1.A2 (+12V), J1.A3 (+12V), J1.B1 (+12V), J1.B2 (+12V), J1.B3 (+12V); also elsewhere on the board

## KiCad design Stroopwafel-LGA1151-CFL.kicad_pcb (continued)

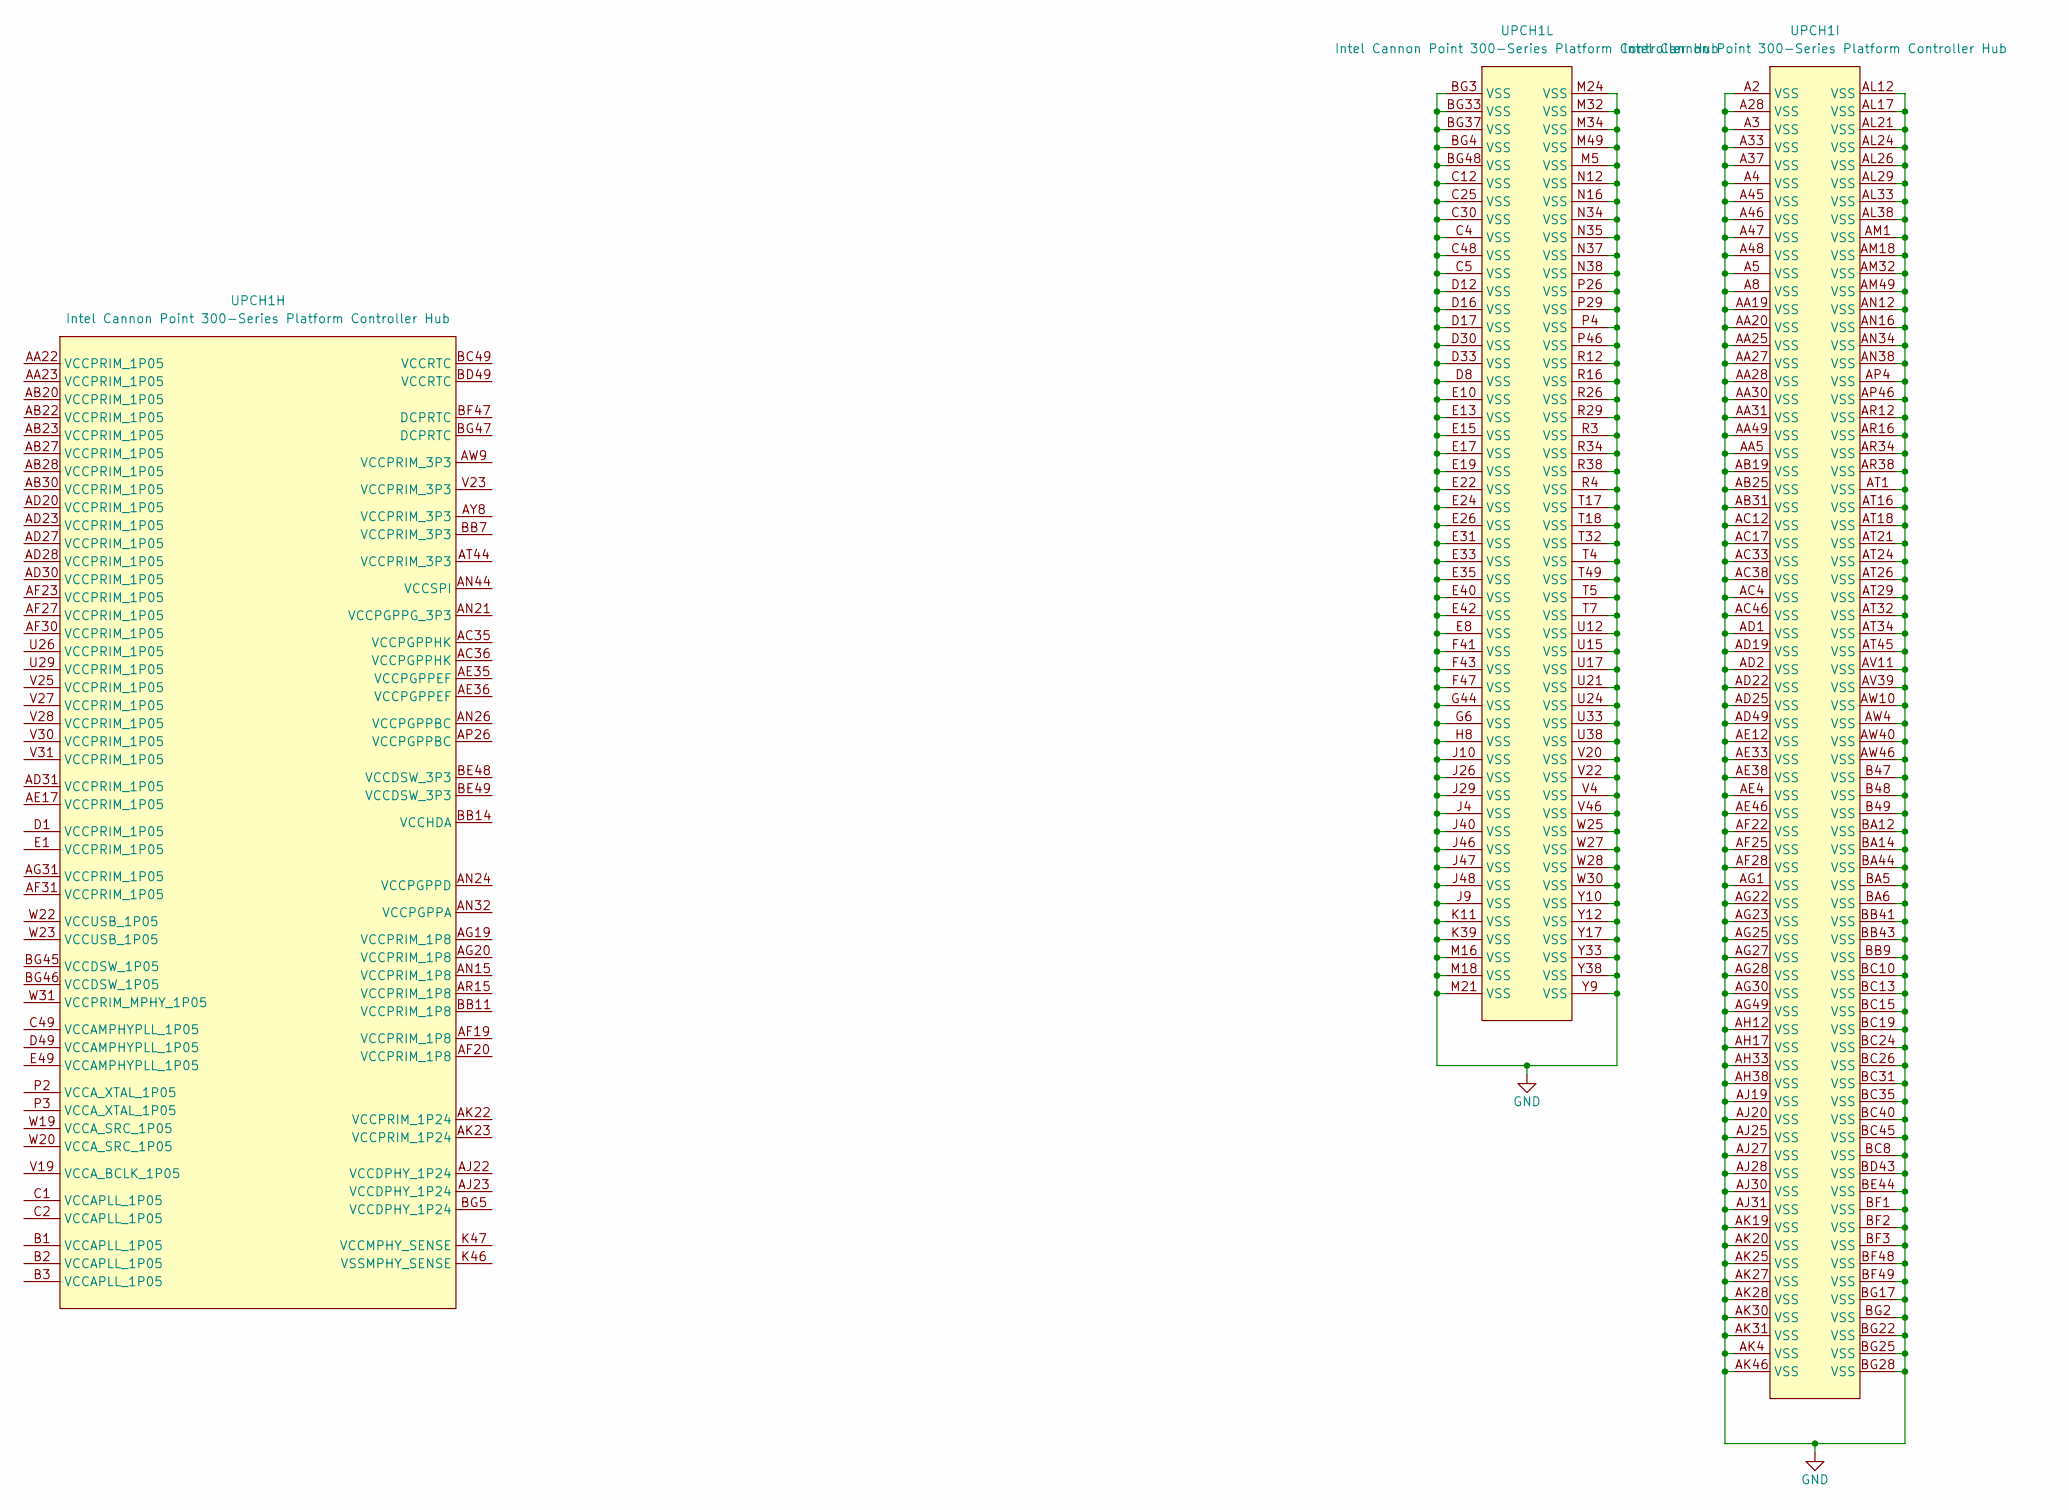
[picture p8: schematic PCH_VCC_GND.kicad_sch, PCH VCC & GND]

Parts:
UPCH1: Intel Cannon Point 300-Series Platform Controller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; CNP-H_BGA_874P-T

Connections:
GND: UPCH1.A2 (VSS), UPCH1.A3 (VSS), UPCH1.A4 (VSS), UPCH1.A5 (VSS), UPCH1.A8 (VSS), UPCH1.A28 (VSS), UPCH1.A33 (VSS), UPCH1.A37 (VSS), UPCH1.A45 (VSS), UPCH1.A46 (VSS), UPCH1.A47 (VSS), UPCH1.A48 (VSS), UPCH1.AA5 (VSS), UPCH1.AA19 (VSS), UPCH1.AA20 (VSS), UPCH1.AA25 (VSS), UPCH1.AA27 (VSS), UPCH1.AA28 (VSS), UPCH1.AA30 (VSS), UPCH1.AA31 (VSS), UPCH1.AA49 (VSS), UPCH1.AB19 (VSS), UPCH1.AB25 (VSS), UPCH1.AB31 (VSS), UPCH1.AC4 (VSS), UPCH1.AC12 (VSS), UPCH1.AC17 (VSS), UPCH1.AC33 (VSS), UPCH1.AC38 (VSS), UPCH1.AC46 (VSS), UPCH1.AD1 (VSS), UPCH1.AD2 (VSS), UPCH1.AD19 (VSS), UPCH1.AD22 (VSS), UPCH1.AD25 (VSS), UPCH1.AD49 (VSS), UPCH1.AE4 (VSS), UPCH1.AE12 (VSS), UPCH1.AE33 (VSS), UPCH1.AE38 (VSS), UPCH1.AE46 (VSS), UPCH1.AF22 (VSS), UPCH1.AF25 (VSS), UPCH1.AF28 (VSS), UPCH1.AG1 (VSS), UPCH1.AG22 (VSS), UPCH1.AG23 (VSS), UPCH1.AG25 (VSS), UPCH1.AG27 (VSS), UPCH1.AG28 (VSS), UPCH1.AG30 (VSS), UPCH1.AG49 (VSS), UPCH1.AH12 (VSS), UPCH1.AH17 (VSS), UPCH1.AH33 (VSS), UPCH1.AH38 (VSS), UPCH1.AJ19 (VSS), UPCH1.AJ20 (VSS), UPCH1.AJ25 (VSS), UPCH1.AJ27 (VSS), UPCH1.AJ28 (VSS), UPCH1.AJ30 (VSS), UPCH1.AJ31 (VSS), UPCH1.AK4 (VSS), UPCH1.AK19 (VSS), UPCH1.AK20 (VSS), UPCH1.AK25 (VSS), UPCH1.AK27 (VSS), UPCH1.AK28 (VSS), UPCH1.AK30 (VSS), UPCH1.AK31 (VSS), UPCH1.AK46 (VSS), UPCH1.AL12 (VSS), UPCH1.AL17 (VSS), UPCH1.AL21 (VSS), UPCH1.AL24 (VSS), UPCH1.AL26 (VSS), UPCH1.AL29 (VSS), UPCH1.AL33 (VSS), UPCH1.AL38 (VSS), UPCH1.AM1 (VSS), UPCH1.AM18 (VSS), UPCH1.AM32 (VSS), UPCH1.AM49 (VSS), UPCH1.AN12 (VSS), UPCH1.AN16 (VSS), UPCH1.AN34 (VSS), UPCH1.AN38 (VSS), UPCH1.AP4 (VSS), UPCH1.AP46 (VSS), UPCH1.AR12 (VSS), UPCH1.AR16 (VSS), UPCH1.AR34 (VSS), UPCH1.AR38 (VSS), UPCH1.AT1 (VSS), UPCH1.AT16 (VSS), UPCH1.AT18 (VSS), UPCH1.AT21 (VSS), UPCH1.AT24 (VSS), UPCH1.AT26 (VSS), UPCH1.AT29 (VSS), UPCH1.AT32 (VSS), UPCH1.AT34 (VSS), UPCH1.AT45 (VSS), UPCH1.AV11 (VSS), UPCH1.AV39 (VSS), UPCH1.AW4 (VSS), UPCH1.AW10 (VSS), UPCH1.AW40 (VSS), UPCH1.AW46 (VSS), UPCH1.B47 (VSS), UPCH1.B48 (VSS), UPCH1.B49 (VSS), UPCH1.BA5 (VSS), UPCH1.BA6 (VSS), UPCH1.BA12 (VSS), UPCH1.BA14 (VSS), UPCH1.BA44 (VSS), UPCH1.BB9 (VSS), UPCH1.BB41 (VSS), UPCH1.BB43 (VSS), UPCH1.BC8 (VSS), UPCH1.BC10 (VSS), UPCH1.BC13 (VSS), UPCH1.BC15 (VSS), UPCH1.BC19 (VSS), UPCH1.BC24 (VSS), UPCH1.BC26 (VSS), UPCH1.BC31 (VSS), UPCH1.BC35 (VSS), UPCH1.BC40 (VSS), UPCH1.BC45 (VSS), UPCH1.BD43 (VSS), UPCH1.BE44 (VSS), UPCH1.BF1 (VSS), UPCH1.BF2 (VSS), UPCH1.BF3 (VSS), UPCH1.BF48 (VSS), UPCH1.BF49 (VSS), UPCH1.BG2 (VSS), UPCH1.BG3 (VSS), UPCH1.BG4 (VSS), UPCH1.BG17 (VSS), UPCH1.BG22 (VSS), UPCH1.BG25 (VSS), UPCH1.BG28 (VSS), UPCH1.BG33 (VSS), UPCH1.BG37 (VSS), UPCH1.BG48 (VSS), UPCH1.C4 (VSS), UPCH1.C5 (VSS), UPCH1.C12 (VSS), UPCH1.C25 (VSS), UPCH1.C30 (VSS), UPCH1.C48 (VSS), UPCH1.D8 (VSS), UPCH1.D12 (VSS), UPCH1.D16 (VSS), UPCH1.D17 (VSS), UPCH1.D30 (VSS), UPCH1.D33 (VSS), UPCH1.E8 (VSS), UPCH1.E10 (VSS), UPCH1.E13 (VSS), UPCH1.E15 (VSS), UPCH1.E17 (VSS), UPCH1.E19 (VSS), UPCH1.E22 (VSS), UPCH1.E24 (VSS), UPCH1.E26 (VSS), UPCH1.E31 (VSS), UPCH1.E33 (VSS), UPCH1.E35 (VSS), UPCH1.E40 (VSS), UPCH1.E42 (VSS), UPCH1.F41 (VSS), UPCH1.F43 (VSS), UPCH1.F47 (VSS), UPCH1.G6 (VSS), UPCH1.G44 (VSS), UPCH1.H8 (VSS), UPCH1.J4 (VSS), UPCH1.J9 (VSS), UPCH1.J10 (VSS), UPCH1.J26 (VSS), UPCH1.J29 (VSS), UPCH1.J40 (VSS), UPCH1.J46 (VSS), UPCH1.J47 (VSS), UPCH1.J48 (VSS), UPCH1.K11 (VSS), UPCH1.K39 (VSS), UPCH1.M5 (VSS), UPCH1.M16 (VSS), UPCH1.M18 (VSS), UPCH1.M21 (VSS), UPCH1.M24 (VSS), UPCH1.M32 (VSS), UPCH1.M34 (VSS), UPCH1.M49 (VSS), UPCH1.N12 (VSS), UPCH1.N16 (VSS), UPCH1.N34 (VSS), UPCH1.N35 (VSS), UPCH1.N37 (VSS), UPCH1.N38 (VSS), UPCH1.P4 (VSS), UPCH1.P26 (VSS), UPCH1.P29 (VSS), UPCH1.P46 (VSS), UPCH1.R3 (VSS), UPCH1.R4 (VSS), UPCH1.R12 (VSS), UPCH1.R16 (VSS), UPCH1.R26 (VSS), UPCH1.R29 (VSS), UPCH1.R34 (VSS), UPCH1.R38 (VSS), UPCH1.T4 (VSS), UPCH1.T5 (VSS), UPCH1.T7 (VSS), UPCH1.T17 (VSS), UPCH1.T18 (VSS), UPCH1.T32 (VSS), UPCH1.T49 (VSS), UPCH1.U12 (VSS), UPCH1.U15 (VSS), UPCH1.U17 (VSS), UPCH1.U21 (VSS), UPCH1.U24 (VSS), UPCH1.U33 (VSS), UPCH1.U38 (VSS), UPCH1.V4 (VSS), UPCH1.V20 (VSS), UPCH1.V22 (VSS), UPCH1.V46 (VSS), UPCH1.W25 (VSS), UPCH1.W27 (VSS), UPCH1.W28 (VSS), UPCH1.W30 (VSS), UPCH1.Y9 (VSS), UPCH1.Y10 (VSS), UPCH1.Y12 (VSS), UPCH1.Y17 (VSS), UPCH1.Y33 (VSS), UPCH1.Y38 (VSS); also elsewhere on the board

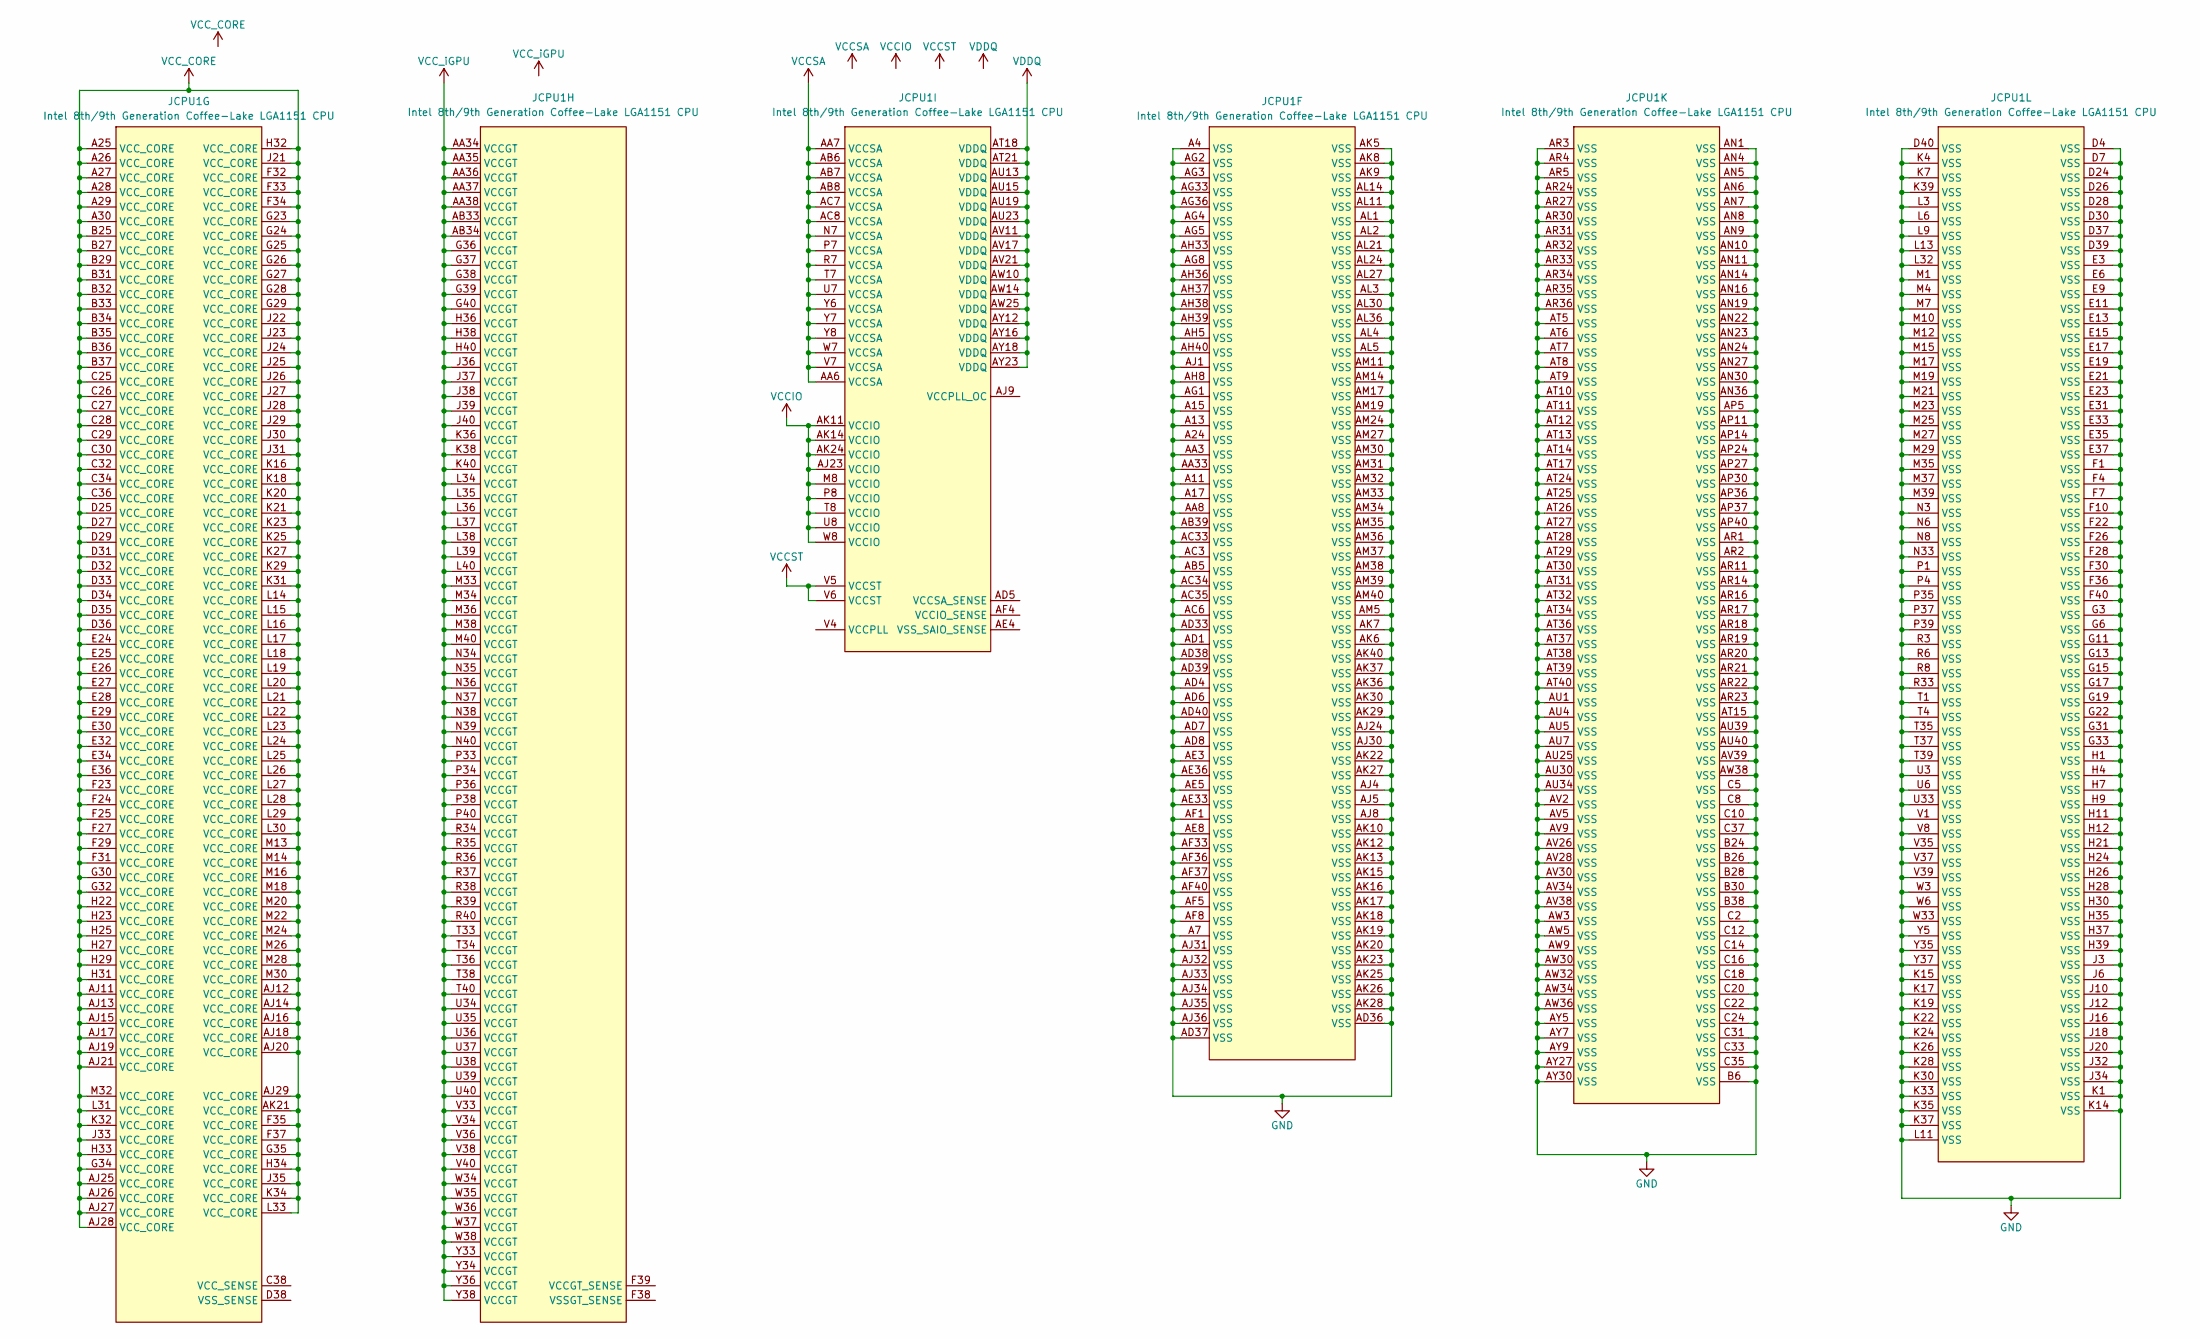
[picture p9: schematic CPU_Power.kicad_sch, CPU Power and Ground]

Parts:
JCPU1: Intel 8th/9th Generation Coffee-Lake LGA1151 CPU; LGA-1151_L47.1-W42.5-P0.91_PE115127-4041-01H

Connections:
GND: JCPU1.A4 (VSS), JCPU1.A7 (VSS), JCPU1.A11 (VSS), JCPU1.A13 (VSS), JCPU1.A15 (VSS), JCPU1.A17 (VSS), JCPU1.A24 (VSS), JCPU1.AA3 (VSS), JCPU1.AA8 (VSS), JCPU1.AA33 (VSS), JCPU1.AB5 (VSS), JCPU1.AB39 (VSS), JCPU1.AC3 (VSS), JCPU1.AC6 (VSS), JCPU1.AC33 (VSS), JCPU1.AC34 (VSS), JCPU1.AC35 (VSS), JCPU1.AD1 (VSS), JCPU1.AD4 (VSS), JCPU1.AD6 (VSS), JCPU1.AD7 (VSS), JCPU1.AD8 (VSS), JCPU1.AD33 (VSS), JCPU1.AD36 (VSS), JCPU1.AD37 (VSS), JCPU1.AD38 (VSS), JCPU1.AD39 (VSS), JCPU1.AD40 (VSS), JCPU1.AE3 (VSS), JCPU1.AE5 (VSS), JCPU1.AE8 (VSS), JCPU1.AE33 (VSS), JCPU1.AE36 (VSS), JCPU1.AF1 (VSS), JCPU1.AF5 (VSS), JCPU1.AF8 (VSS), JCPU1.AF33 (VSS), JCPU1.AF36 (VSS), JCPU1.AF37 (VSS), JCPU1.AF40 (VSS), JCPU1.AG1 (VSS), JCPU1.AG2 (VSS), JCPU1.AG3 (VSS), JCPU1.AG4 (VSS), JCPU1.AG5 (VSS), JCPU1.AG8 (VSS), JCPU1.AG33 (VSS), JCPU1.AG36 (VSS), JCPU1.AH5 (VSS), JCPU1.AH8 (VSS), JCPU1.AH33 (VSS), JCPU1.AH36 (VSS), JCPU1.AH37 (VSS), JCPU1.AH38 (VSS), JCPU1.AH39 (VSS), JCPU1.AH40 (VSS), JCPU1.AJ1 (VSS), JCPU1.AJ4 (VSS), JCPU1.AJ5 (VSS), JCPU1.AJ8 (VSS), JCPU1.AJ24 (VSS), JCPU1.AJ30 (VSS), JCPU1.AJ31 (VSS), JCPU1.AJ32 (VSS), JCPU1.AJ33 (VSS), JCPU1.AJ34 (VSS), JCPU1.AJ35 (VSS), JCPU1.AJ36 (VSS), JCPU1.AK5 (VSS), JCPU1.AK6 (VSS), JCPU1.AK7 (VSS), JCPU1.AK8 (VSS), JCPU1.AK9 (VSS), JCPU1.AK10 (VSS), JCPU1.AK12 (VSS), JCPU1.AK13 (VSS), JCPU1.AK15 (VSS), JCPU1.AK16 (VSS), JCPU1.AK17 (VSS), JCPU1.AK18 (VSS), JCPU1.AK19 (VSS), JCPU1.AK20 (VSS), JCPU1.AK22 (VSS), JCPU1.AK23 (VSS), JCPU1.AK25 (VSS), JCPU1.AK26 (VSS), JCPU1.AK27 (VSS), JCPU1.AK28 (VSS), JCPU1.AK29 (VSS), JCPU1.AK30 (VSS), JCPU1.AK36 (VSS), JCPU1.AK37 (VSS), JCPU1.AK40 (VSS), JCPU1.AL1 (VSS), JCPU1.AL2 (VSS), JCPU1.AL3 (VSS), JCPU1.AL4 (VSS), JCPU1.AL5 (VSS), JCPU1.AL11 (VSS), JCPU1.AL14 (VSS), JCPU1.AL21 (VSS), JCPU1.AL24 (VSS), JCPU1.AL27 (VSS), JCPU1.AL30 (VSS), JCPU1.AL36 (VSS), JCPU1.AM5 (VSS), JCPU1.AM11 (VSS), JCPU1.AM14 (VSS), JCPU1.AM17 (VSS), JCPU1.AM19 (VSS), JCPU1.AM24 (VSS), JCPU1.AM27 (VSS), JCPU1.AM30 (VSS), JCPU1.AM31 (VSS), JCPU1.AM32 (VSS), JCPU1.AM33 (VSS), JCPU1.AM34 (VSS), JCPU1.AM35 (VSS), JCPU1.AM36 (VSS), JCPU1.AM37 (VSS), JCPU1.AM38 (VSS), JCPU1.AM39 (VSS), JCPU1.AM40 (VSS), JCPU1.AN1 (VSS), JCPU1.AN4 (VSS), JCPU1.AN5 (VSS), JCPU1.AN6 (VSS), JCPU1.AN7 (VSS), JCPU1.AN8 (VSS), JCPU1.AN9 (VSS), JCPU1.AN10 (VSS), JCPU1.AN11 (VSS), JCPU1.AN14 (VSS), JCPU1.AN16 (VSS), JCPU1.AN19 (VSS), JCPU1.AN22 (VSS), JCPU1.AN23 (VSS), JCPU1.AN24 (VSS), JCPU1.AN27 (VSS), JCPU1.AN30 (VSS), JCPU1.AN36 (VSS), JCPU1.AP5 (VSS), JCPU1.AP11 (VSS), JCPU1.AP14 (VSS), JCPU1.AP24 (VSS), JCPU1.AP27 (VSS), JCPU1.AP30 (VSS), JCPU1.AP36 (VSS), JCPU1.AP37 (VSS), JCPU1.AP40 (VSS), JCPU1.AR1 (VSS), JCPU1.AR2 (VSS), JCPU1.AR3 (VSS), JCPU1.AR4 (VSS), JCPU1.AR5 (VSS), JCPU1.AR11 (VSS), JCPU1.AR14 (VSS), JCPU1.AR16 (VSS), JCPU1.AR17 (VSS), JCPU1.AR18 (VSS), JCPU1.AR19 (VSS), JCPU1.AR20 (VSS), JCPU1.AR21 (VSS), JCPU1.AR22 (VSS), JCPU1.AR23 (VSS), JCPU1.AR24 (VSS), JCPU1.AR27 (VSS), JCPU1.AR30 (VSS), JCPU1.AR31 (VSS), JCPU1.AR32 (VSS), JCPU1.AR33 (VSS), JCPU1.AR34 (VSS), JCPU1.AR35 (VSS), JCPU1.AR36 (VSS), JCPU1.AT5 (VSS), JCPU1.AT6 (VSS), JCPU1.AT7 (VSS), JCPU1.AT8 (VSS), JCPU1.AT9 (VSS), JCPU1.AT10 (VSS), JCPU1.AT11 (VSS), JCPU1.AT12 (VSS), JCPU1.AT13 (VSS), JCPU1.AT14 (VSS), JCPU1.AT15 (VSS), JCPU1.AT17 (VSS), JCPU1.AT24 (VSS), JCPU1.AT25 (VSS), JCPU1.AT26 (VSS), JCPU1.AT27 (VSS), JCPU1.AT28 (VSS), JCPU1.AT29 (VSS), JCPU1.AT30 (VSS), JCPU1.AT31 (VSS), JCPU1.AT32 (VSS), JCPU1.AT34 (VSS), JCPU1.AT36 (VSS), JCPU1.AT37 (VSS), JCPU1.AT38 (VSS), JCPU1.AT39 (VSS), JCPU1.AT40 (VSS), JCPU1.AU1 (VSS), JCPU1.AU4 (VSS), JCPU1.AU5 (VSS), JCPU1.AU7 (VSS), JCPU1.AU25 (VSS), JCPU1.AU30 (VSS), JCPU1.AU34 (VSS), JCPU1.AU39 (VSS), JCPU1.AU40 (VSS), JCPU1.AV2 (VSS), JCPU1.AV5 (VSS), JCPU1.AV9 (VSS), JCPU1.AV26 (VSS), JCPU1.AV28 (VSS), JCPU1.AV30 (VSS), JCPU1.AV34 (VSS), JCPU1.AV38 (VSS), JCPU1.AV39 (VSS), JCPU1.AW3 (VSS), JCPU1.AW5 (VSS), JCPU1.AW9 (VSS), JCPU1.AW30 (VSS), JCPU1.AW32 (VSS), JCPU1.AW34 (VSS), JCPU1.AW36 (VSS), JCPU1.AW38 (VSS), JCPU1.AY5 (VSS), JCPU1.AY7 (VSS), JCPU1.AY9 (VSS), JCPU1.AY27 (VSS), JCPU1.AY30 (VSS), JCPU1.B6 (VSS), JCPU1.B24 (VSS), JCPU1.B26 (VSS), JCPU1.B28 (VSS), JCPU1.B30 (VSS), JCPU1.B38 (VSS), JCPU1.C2 (VSS), JCPU1.C5 (VSS), JCPU1.C8 (VSS), JCPU1.C10 (VSS), JCPU1.C12 (VSS), JCPU1.C14 (VSS), JCPU1.C16 (VSS), JCPU1.C18 (VSS), JCPU1.C20 (VSS), JCPU1.C22 (VSS), JCPU1.C24 (VSS), JCPU1.C31 (VSS), JCPU1.C33 (VSS), JCPU1.C35 (VSS), JCPU1.C37 (VSS), JCPU1.D4 (VSS), JCPU1.D7 (VSS), JCPU1.D24 (VSS), JCPU1.D26 (VSS), JCPU1.D28 (VSS), JCPU1.D30 (VSS), JCPU1.D37 (VSS), JCPU1.D39 (VSS), JCPU1.D40 (VSS), JCPU1.E3 (VSS), JCPU1.E6 (VSS), JCPU1.E9 (VSS), JCPU1.E11 (VSS), JCPU1.E13 (VSS), JCPU1.E15 (VSS), JCPU1.E17 (VSS), JCPU1.E19 (VSS), JCPU1.E21 (VSS), JCPU1.E23 (VSS), JCPU1.E31 (VSS), JCPU1.E33 (VSS), JCPU1.E35 (VSS), JCPU1.E37 (VSS), JCPU1.F1 (VSS), JCPU1.F4 (VSS), JCPU1.F7 (VSS), JCPU1.F10 (VSS), JCPU1.F22 (VSS), JCPU1.F26 (VSS), JCPU1.F28 (VSS), JCPU1.F30 (VSS), JCPU1.F36 (VSS), JCPU1.F40 (VSS), JCPU1.G3 (VSS), JCPU1.G6 (VSS), JCPU1.G11 (VSS), JCPU1.G13 (VSS), JCPU1.G15 (VSS), JCPU1.G17 (VSS), JCPU1.G19 (VSS), JCPU1.G22 (VSS), JCPU1.G31 (VSS), JCPU1.G33 (VSS), JCPU1.H1 (VSS), JCPU1.H4 (VSS), JCPU1.H7 (VSS), JCPU1.H9 (VSS), JCPU1.H11 (VSS), JCPU1.H12 (VSS), JCPU1.H21 (VSS), JCPU1.H24 (VSS), JCPU1.H26 (VSS), JCPU1.H28 (VSS), JCPU1.H30 (VSS), JCPU1.H35 (VSS), JCPU1.H37 (VSS), JCPU1.H39 (VSS), JCPU1.J3 (VSS), JCPU1.J6 (VSS), JCPU1.J10 (VSS), JCPU1.J12 (VSS), JCPU1.J16 (VSS), JCPU1.J18 (VSS), JCPU1.J20 (VSS), JCPU1.J32 (VSS), JCPU1.J34 (VSS), JCPU1.K1 (VSS), JCPU1.K4 (VSS), JCPU1.K7 (VSS), JCPU1.K14 (VSS), JCPU1.K15 (VSS), JCPU1.K17 (VSS), JCPU1.K19 (VSS), JCPU1.K22 (VSS), JCPU1.K24 (VSS), JCPU1.K26 (VSS), JCPU1.K28 (VSS), JCPU1.K30 (VSS), JCPU1.K33 (VSS), JCPU1.K35 (VSS), JCPU1.K37 (VSS), JCPU1.K39 (VSS), JCPU1.L3 (VSS), JCPU1.L6 (VSS), JCPU1.L9 (VSS), JCPU1.L11 (VSS), JCPU1.L13 (VSS), JCPU1.L32 (VSS), JCPU1.M1 (VSS), JCPU1.M4 (VSS), JCPU1.M7 (VSS), JCPU1.M10 (VSS), JCPU1.M12 (VSS), JCPU1.M15 (VSS), JCPU1.M17 (VSS), JCPU1.M19 (VSS), JCPU1.M21 (VSS), JCPU1.M23 (VSS), JCPU1.M25 (VSS), JCPU1.M27 (VSS), JCPU1.M29 (VSS), JCPU1.M35 (VSS), JCPU1.M37 (VSS), JCPU1.M39 (VSS), JCPU1.N3 (VSS), JCPU1.N6 (VSS), JCPU1.N8 (VSS), JCPU1.N33 (VSS), JCPU1.P1 (VSS), JCPU1.P4 (VSS), JCPU1.P35 (VSS), JCPU1.P37 (VSS), JCPU1.P39 (VSS), JCPU1.R3 (VSS), JCPU1.R6 (VSS), JCPU1.R8 (VSS), JCPU1.R33 (VSS), JCPU1.T1 (VSS), JCPU1.T4 (VSS), JCPU1.T35 (VSS), JCPU1.T37 (VSS), JCPU1.T39 (VSS), JCPU1.U3 (VSS), JCPU1.U6 (VSS), JCPU1.U33 (VSS), JCPU1.V1 (VSS), JCPU1.V8 (VSS), JCPU1.V35 (VSS), JCPU1.V37 (VSS), JCPU1.V39 (VSS), JCPU1.W3 (VSS), JCPU1.W6 (VSS), JCPU1.W33 (VSS), JCPU1.Y5 (VSS), JCPU1.Y35 (VSS), JCPU1.Y37 (VSS); also elsewhere on the board
VCCIO: JCPU1.AJ23 (VCCIO), JCPU1.AK11 (VCCIO), JCPU1.AK14 (VCCIO), JCPU1.AK24 (VCCIO), JCPU1.M8 (VCCIO), JCPU1.P8 (VCCIO), JCPU1.T8 (VCCIO), JCPU1.U8 (VCCIO), JCPU1.W8 (VCCIO); also elsewhere on the board
VCCSA: JCPU1.AA6 (VCCSA), JCPU1.AA7 (VCCSA), JCPU1.AB6 (VCCSA), JCPU1.AB7 (VCCSA), JCPU1.AB8 (VCCSA), JCPU1.AC7 (VCCSA), JCPU1.AC8 (VCCSA), JCPU1.N7 (VCCSA), JCPU1.P7 (VCCSA), JCPU1.R7 (VCCSA), JCPU1.T7 (VCCSA), JCPU1.U7 (VCCSA), JCPU1.V7 (VCCSA), JCPU1.W7 (VCCSA), JCPU1.Y6 (VCCSA), JCPU1.Y7 (VCCSA), JCPU1.Y8 (VCCSA)
VCCST: JCPU1.V5 (VCCST), JCPU1.V6 (VCCST); also elsewhere on the board
VCC_CORE: JCPU1.A25 (VCC_CORE), JCPU1.A26 (VCC_CORE), JCPU1.A27 (VCC_CORE), JCPU1.A28 (VCC_CORE), JCPU1.A29 (VCC_CORE), JCPU1.A30 (VCC_CORE), JCPU1.AJ11 (VCC_CORE), JCPU1.AJ12 (VCC_CORE), JCPU1.AJ13 (VCC_CORE), JCPU1.AJ14 (VCC_CORE), JCPU1.AJ15 (VCC_CORE), JCPU1.AJ16 (VCC_CORE), JCPU1.AJ17 (VCC_CORE), JCPU1.AJ18 (VCC_CORE), JCPU1.AJ19 (VCC_CORE), JCPU1.AJ20 (VCC_CORE), JCPU1.AJ21 (VCC_CORE), JCPU1.AJ25 (VCC_CORE), JCPU1.AJ26 (VCC_CORE), JCPU1.AJ27 (VCC_CORE), JCPU1.AJ28 (VCC_CORE), JCPU1.AJ29 (VCC_CORE), JCPU1.AK21 (VCC_CORE), JCPU1.B25 (VCC_CORE), JCPU1.B27 (VCC_CORE), JCPU1.B29 (VCC_CORE), JCPU1.B31 (VCC_CORE), JCPU1.B32 (VCC_CORE), JCPU1.B33 (VCC_CORE), JCPU1.B34 (VCC_CORE), JCPU1.B35 (VCC_CORE), JCPU1.B36 (VCC_CORE), JCPU1.B37 (VCC_CORE), JCPU1.C25 (VCC_CORE), JCPU1.C26 (VCC_CORE), JCPU1.C27 (VCC_CORE), JCPU1.C28 (VCC_CORE), JCPU1.C29 (VCC_CORE), JCPU1.C30 (VCC_CORE), JCPU1.C32 (VCC_CORE), JCPU1.C34 (VCC_CORE), JCPU1.C36 (VCC_CORE), JCPU1.D25 (VCC_CORE), JCPU1.D27 (VCC_CORE), JCPU1.D29 (VCC_CORE), JCPU1.D31 (VCC_CORE), JCPU1.D32 (VCC_CORE), JCPU1.D33 (VCC_CORE), JCPU1.D34 (VCC_CORE), JCPU1.D35 (VCC_CORE), JCPU1.D36 (VCC_CORE), JCPU1.E24 (VCC_CORE), JCPU1.E25 (VCC_CORE), JCPU1.E26 (VCC_CORE), JCPU1.E27 (VCC_CORE), JCPU1.E28 (VCC_CORE), JCPU1.E29 (VCC_CORE), JCPU1.E30 (VCC_CORE), JCPU1.E32 (VCC_CORE), JCPU1.E34 (VCC_CORE), JCPU1.E36 (VCC_CORE), JCPU1.F23 (VCC_CORE), JCPU1.F24 (VCC_CORE), JCPU1.F25 (VCC_CORE), JCPU1.F27 (VCC_CORE), JCPU1.F29 (VCC_CORE), JCPU1.F31 (VCC_CORE), JCPU1.F32 (VCC_CORE), JCPU1.F33 (VCC_CORE), JCPU1.F34 (VCC_CORE), JCPU1.F35 (VCC_CORE), JCPU1.F37 (VCC_CORE), JCPU1.G23 (VCC_CORE), JCPU1.G24 (VCC_CORE), JCPU1.G25 (VCC_CORE), JCPU1.G26 (VCC_CORE), JCPU1.G27 (VCC_CORE), JCPU1.G28 (VCC_CORE), JCPU1.G29 (VCC_CORE), JCPU1.G30 (VCC_CORE), JCPU1.G32 (VCC_CORE), JCPU1.G34 (VCC_CORE), JCPU1.G35 (VCC_CORE), JCPU1.H22 (VCC_CORE), JCPU1.H23 (VCC_CORE), JCPU1.H25 (VCC_CORE), JCPU1.H27 (VCC_CORE), JCPU1.H29 (VCC_CORE), JCPU1.H31 (VCC_CORE), JCPU1.H32 (VCC_CORE), JCPU1.H33 (VCC_CORE), JCPU1.H34 (VCC_CORE), JCPU1.J21 (VCC_CORE), JCPU1.J22 (VCC_CORE), JCPU1.J23 (VCC_CORE), JCPU1.J24 (VCC_CORE), JCPU1.J25 (VCC_CORE), JCPU1.J26 (VCC_CORE), JCPU1.J27 (VCC_CORE), JCPU1.J28 (VCC_CORE), JCPU1.J29 (VCC_CORE), JCPU1.J30 (VCC_CORE), JCPU1.J31 (VCC_CORE), JCPU1.J33 (VCC_CORE), JCPU1.J35 (VCC_CORE), JCPU1.K16 (VCC_CORE), JCPU1.K18 (VCC_CORE), JCPU1.K20 (VCC_CORE), JCPU1.K21 (VCC_CORE), JCPU1.K23 (VCC_CORE), JCPU1.K25 (VCC_CORE), JCPU1.K27 (VCC_CORE), JCPU1.K29 (VCC_CORE), JCPU1.K31 (VCC_CORE), JCPU1.K32 (VCC_CORE), JCPU1.K34 (VCC_CORE), JCPU1.L14 (VCC_CORE), JCPU1.L15 (VCC_CORE), JCPU1.L16 (VCC_CORE), JCPU1.L17 (VCC_CORE), JCPU1.L18 (VCC_CORE), JCPU1.L19 (VCC_CORE), JCPU1.L20 (VCC_CORE), JCPU1.L21 (VCC_CORE), JCPU1.L22 (VCC_CORE), JCPU1.L23 (VCC_CORE), JCPU1.L24 (VCC_CORE), JCPU1.L25 (VCC_CORE), JCPU1.L26 (VCC_CORE), JCPU1.L27 (VCC_CORE), JCPU1.L28 (VCC_CORE), JCPU1.L29 (VCC_CORE), JCPU1.L30 (VCC_CORE), JCPU1.L31 (VCC_CORE), JCPU1.L33 (VCC_CORE), JCPU1.M13 (VCC_CORE), JCPU1.M14 (VCC_CORE), JCPU1.M16 (VCC_CORE), JCPU1.M18 (VCC_CORE), JCPU1.M20 (VCC_CORE), JCPU1.M22 (VCC_CORE), JCPU1.M24 (VCC_CORE), JCPU1.M26 (VCC_CORE), JCPU1.M28 (VCC_CORE), JCPU1.M30 (VCC_CORE), JCPU1.M32 (VCC_CORE)
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

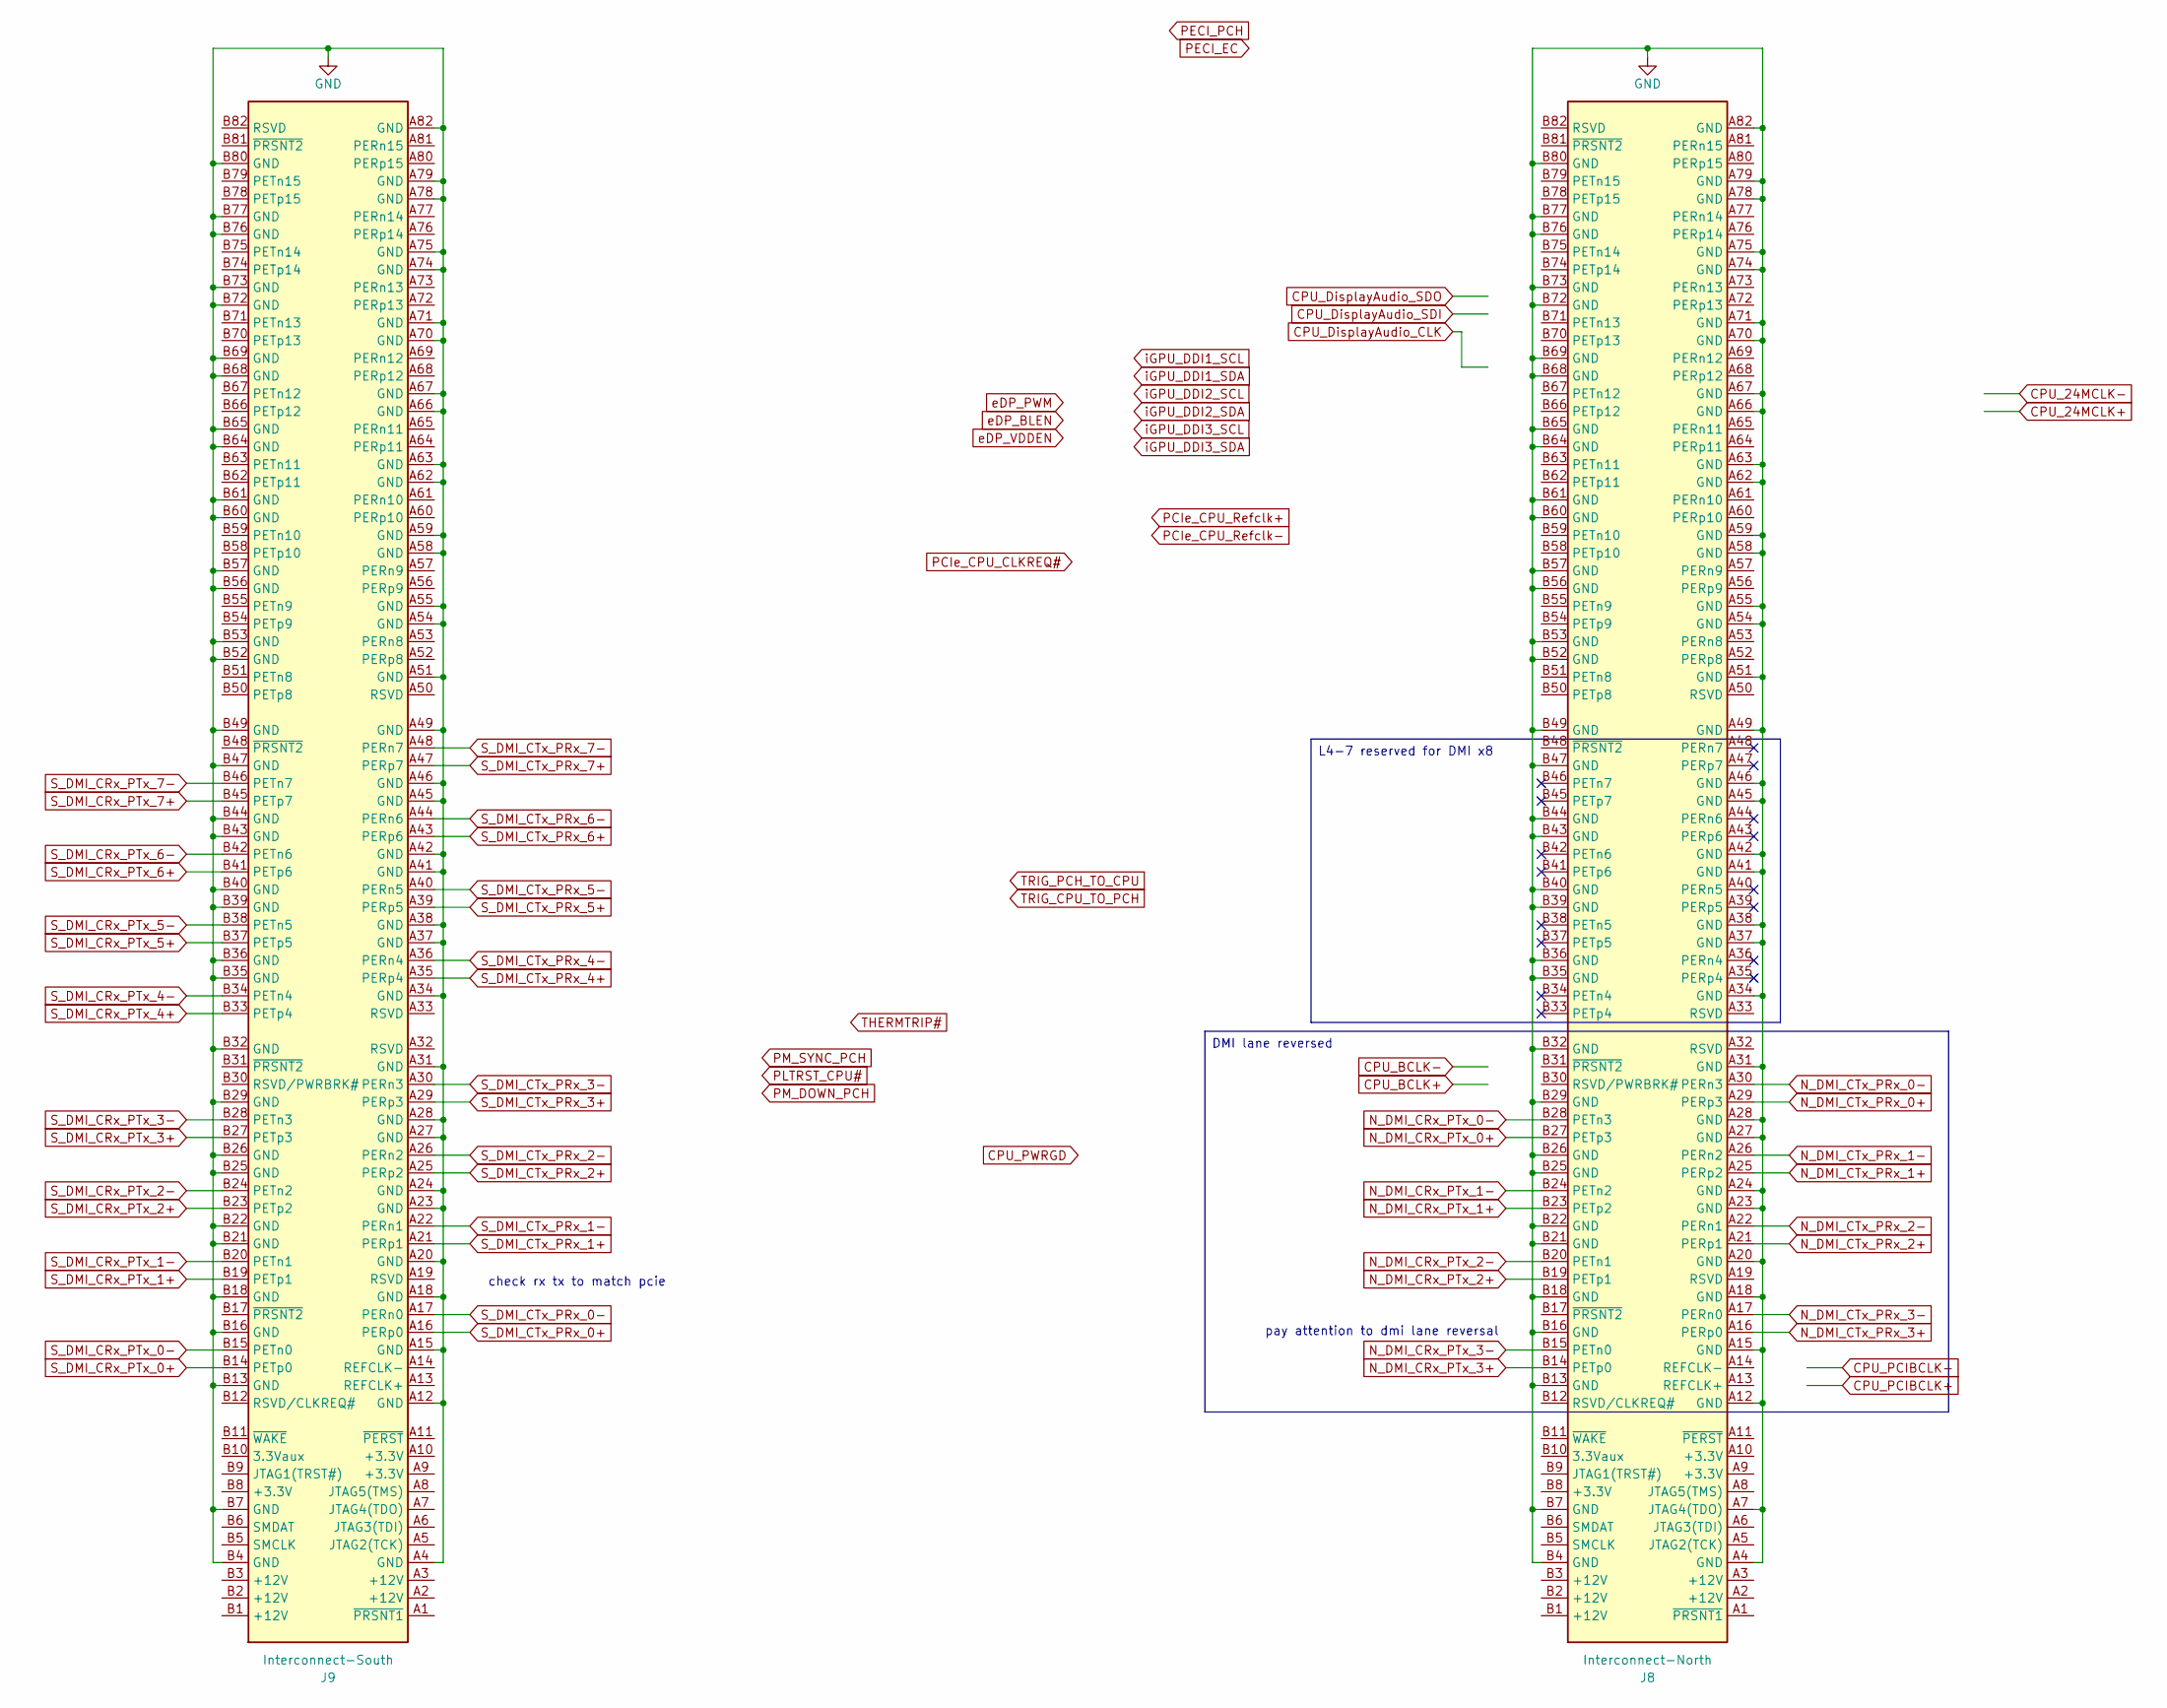
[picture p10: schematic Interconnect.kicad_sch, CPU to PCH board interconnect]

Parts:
J8: Interconnect-North; PCIe_x16_straddlemount
J9: Interconnect-South; BUS_PCIexpress_x16

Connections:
GND: J8.A4 (GND), J8.A7 (JTAG4(TDO)), J8.A12 (GND), J8.A15 (GND), J8.A18 (GND), J8.A20 (GND), J8.A23 (GND), J8.A24 (GND), J8.A27 (GND), J8.A28 (GND), J8.A31 (GND), J8.A34 (GND), J8.A37 (GND), J8.A38 (GND), J8.A41 (GND), J8.A42 (GND), J8.A45 (GND), J8.A46 (GND), J8.A49 (GND), J8.A51 (GND), J8.A54 (GND), J8.A55 (GND), J8.A58 (GND), J8.A59 (GND), J8.A62 (GND), J8.A63 (GND), J8.A66 (GND), J8.A67 (GND), J8.A70 (GND), J8.A71 (GND), J8.A74 (GND), J8.A75 (GND), J8.A78 (GND), J8.A79 (GND), J8.A82 (GND), J8.B4 (GND), J8.B7 (GND), J8.B13 (GND), J8.B16 (GND), J8.B18 (GND), J8.B21 (GND), J8.B22 (GND), J8.B25 (GND), J8.B26 (GND), J8.B29 (GND), J8.B32 (GND), J8.B35 (GND), J8.B36 (GND), J8.B39 (GND), J8.B40 (GND), J8.B43 (GND), J8.B44 (GND), J8.B47 (GND), J8.B49 (GND), J8.B52 (GND), J8.B53 (GND), J8.B56 (GND), J8.B57 (GND), J8.B60 (GND), J8.B61 (GND), J8.B64 (GND), J8.B65 (GND), J8.B68 (GND), J8.B69 (GND), J8.B72 (GND), J8.B73 (GND), J8.B76 (GND), J8.B77 (GND), J8.B80 (GND), J9.A4 (GND), J9.A12 (GND), J9.A15 (GND), J9.A18 (GND), J9.A20 (GND), J9.A23 (GND), J9.A24 (GND), J9.A27 (GND), J9.A28 (GND), J9.A31 (GND), J9.A34 (GND), J9.A37 (GND), J9.A38 (GND), J9.A41 (GND), J9.A42 (GND), J9.A45 (GND), J9.A46 (GND), J9.A49 (GND), J9.A51 (GND), J9.A54 (GND), J9.A55 (GND), J9.A58 (GND), J9.A59 (GND), J9.A62 (GND), J9.A63 (GND), J9.A66 (GND), J9.A67 (GND), J9.A70 (GND), J9.A71 (GND), J9.A74 (GND), J9.A75 (GND), J9.A78 (GND), J9.A79 (GND), J9.A82 (GND), J9.B4 (GND), J9.B7 (GND), J9.B13 (GND), J9.B16 (GND), J9.B18 (GND), J9.B21 (GND), J9.B22 (GND), J9.B25 (GND), J9.B26 (GND), J9.B29 (GND), J9.B32 (GND), J9.B35 (GND), J9.B36 (GND), J9.B39 (GND), J9.B40 (GND), J9.B43 (GND), J9.B44 (GND), J9.B47 (GND), J9.B49 (GND), J9.B52 (GND), J9.B53 (GND), J9.B56 (GND), J9.B57 (GND), J9.B60 (GND), J9.B61 (GND), J9.B64 (GND), J9.B65 (GND), J9.B68 (GND), J9.B69 (GND), J9.B72 (GND), J9.B73 (GND), J9.B76 (GND), J9.B77 (GND), J9.B80 (GND); also elsewhere on the board
N_DMI_CRx_PTx_0+: J8.B27 (PETp3); also elsewhere on the board
N_DMI_CRx_PTx_0-: J8.B28 (PETn3); also elsewhere on the board
N_DMI_CRx_PTx_1+: J8.B23 (PETp2); also elsewhere on the board
N_DMI_CRx_PTx_1-: J8.B24 (PETn2); also elsewhere on the board
N_DMI_CRx_PTx_2+: J8.B19 (PETp1); also elsewhere on the board
N_DMI_CRx_PTx_2-: J8.B20 (PETn1); also elsewhere on the board
N_DMI_CRx_PTx_3+: J8.B14 (PETp0); also elsewhere on the board
N_DMI_CRx_PTx_3-: J8.B15 (PETn0); also elsewhere on the board
N_DMI_CTx_PRx_0+: J8.A29 (PERp3); also elsewhere on the board
N_DMI_CTx_PRx_0-: J8.A30 (PERn3); also elsewhere on the board
N_DMI_CTx_PRx_1+: J8.A25 (PERp2); also elsewhere on the board
N_DMI_CTx_PRx_1-: J8.A26 (PERn2); also elsewhere on the board
N_DMI_CTx_PRx_2+: J8.A21 (PERp1); also elsewhere on the board
N_DMI_CTx_PRx_2-: J8.A22 (PERn1); also elsewhere on the board
N_DMI_CTx_PRx_3+: J8.A16 (PERp0); also elsewhere on the board
N_DMI_CTx_PRx_3-: J8.A17 (PERn0); also elsewhere on the board
S_DMI_CRx_PTx_0+: J9.B14 (PETp0); also elsewhere on the board
S_DMI_CRx_PTx_0-: J9.B15 (PETn0); also elsewhere on the board
S_DMI_CRx_PTx_1+: J9.B19 (PETp1); also elsewhere on the board
S_DMI_CRx_PTx_1-: J9.B20 (PETn1); also elsewhere on the board
S_DMI_CRx_PTx_2+: J9.B23 (PETp2); also elsewhere on the board
S_DMI_CRx_PTx_2-: J9.B24 (PETn2); also elsewhere on the board
S_DMI_CRx_PTx_3+: J9.B27 (PETp3); also elsewhere on the board
S_DMI_CRx_PTx_3-: J9.B28 (PETn3); also elsewhere on the board
S_DMI_CRx_PTx_4+: J9.B33 (PETp4); also elsewhere on the board
S_DMI_CRx_PTx_4-: J9.B34 (PETn4); also elsewhere on the board
S_DMI_CRx_PTx_5+: J9.B37 (PETp5); also elsewhere on the board
S_DMI_CRx_PTx_5-: J9.B38 (PETn5); also elsewhere on the board
S_DMI_CRx_PTx_6+: J9.B41 (PETp6); also elsewhere on the board
S_DMI_CRx_PTx_6-: J9.B42 (PETn6); also elsewhere on the board
S_DMI_CRx_PTx_7+: J9.B45 (PETp7); also elsewhere on the board
S_DMI_CRx_PTx_7-: J9.B46 (PETn7); also elsewhere on the board
S_DMI_CTx_PRx_0+: J9.A16 (PERp0); also elsewhere on the board
S_DMI_CTx_PRx_0-: J9.A17 (PERn0); also elsewhere on the board
S_DMI_CTx_PRx_1+: J9.A21 (PERp1); also elsewhere on the board
S_DMI_CTx_PRx_1-: J9.A22 (PERn1); also elsewhere on the board
S_DMI_CTx_PRx_2+: J9.A25 (PERp2); also elsewhere on the board
S_DMI_CTx_PRx_2-: J9.A26 (PERn2); also elsewhere on the board
S_DMI_CTx_PRx_3+: J9.A29 (PERp3); also elsewhere on the board
S_DMI_CTx_PRx_3-: J9.A30 (PERn3); also elsewhere on the board
S_DMI_CTx_PRx_4+: J9.A35 (PERp4); also elsewhere on the board
S_DMI_CTx_PRx_4-: J9.A36 (PERn4); also elsewhere on the board
S_DMI_CTx_PRx_5+: J9.A39 (PERp5); also elsewhere on the board
S_DMI_CTx_PRx_5-: J9.A40 (PERn5); also elsewhere on the board
S_DMI_CTx_PRx_6+: J9.A43 (PERp6); also elsewhere on the board
S_DMI_CTx_PRx_6-: J9.A44 (PERn6); also elsewhere on the board
S_DMI_CTx_PRx_7+: J9.A47 (PERp7); also elsewhere on the board
S_DMI_CTx_PRx_7-: J9.A48 (PERn7); also elsewhere on the board

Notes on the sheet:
pay attention to dmi lane reversal
check rx tx to match pcie
L4-7 reserved for DMI x8
DMI lane reversed

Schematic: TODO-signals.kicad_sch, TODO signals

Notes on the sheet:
connect from CPU vrom VR READY signal to CPU? with some control based on sleep state? look into more when building vrm
This page contains notes about signals I've researched the purpose and functionality of but not yet implemented
Controls enable pin on memory power supply VTT (ACC bus termination) rail, seeing different implementations but each at least buffers or inverts the signal a few times output from CPU, high means power on, low means power off

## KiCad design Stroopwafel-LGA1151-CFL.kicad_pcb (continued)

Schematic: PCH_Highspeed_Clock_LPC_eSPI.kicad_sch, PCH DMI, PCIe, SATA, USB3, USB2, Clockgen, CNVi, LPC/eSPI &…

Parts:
R38: 619Ω; R_0402_1005Metric
R41: 1kΩ; R_0402_1005Metric; not fitted
UPCH1: Intel Cannon Point 300-Series Platform Controller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; CNP-H_BGA_874P-T

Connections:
CPU_24MCLK+: UPCH1.D7 (CLKOUT_CPUNSSC_P); also elsewhere on the board
CPU_24MCLK-: UPCH1.C6 (CLKOUT_CPUNSSC_N); also elsewhere on the board
CPU_BCLK+: UPCH1.B8 (CLKOUT_CPUBCLK_P); also elsewhere on the board
CPU_BCLK-: UPCH1.C8 (CLKOUT_CPUBCLK_N); also elsewhere on the board
CPU_PCIBCLK+: UPCH1.A6 (CLKOUT_CPUPCIBCLK_P); also elsewhere on the board
CPU_PCIBCLK-: UPCH1.B6 (CLKOUT_CPUPCIBCLK_N); also elsewhere on the board
GND: R41.1; also elsewhere on the board
unnamed: R38.1, UPCH1.AD3 (THRMTRIP#)
PCH_x4_1_CLKREQ#: UPCH1.AN29 (GPP_B10/SRCCLKREQ5#); also elsewhere on the board
PCH_x4_1_PCIe_Rx0+: UPCH1.F16 (PCIE1_RXP/USB3.1G1_7_RXP); also elsewhere on the board
PCH_x4_1_PCIe_Rx0-: UPCH1.G17 (PCIE1_RXN/USB3.1G1_7_RXN); also elsewhere on the board
PCH_x4_1_PCIe_Rx1+: UPCH1.P21 (PCIE2_RXP/USB3.1G1_8_RXP); also elsewhere on the board
PCH_x4_1_PCIe_Rx1-: UPCH1.R21 (PCIE2_RXN/USB3.1G1_8_RXN); also elsewhere on the board
PCH_x4_1_PCIe_Rx2+: UPCH1.J18 (PCIE3_RXP/USB3.1G1_9_RXP); also elsewhere on the board
PCH_x4_1_PCIe_Rx2-: UPCH1.K18 (PCIE3_RXN/USB3.1G1_9_RXN); also elsewhere on the board
PCH_x4_1_PCIe_Rx3+: UPCH1.R18 (PCIE4_RXP/USB3.1G1_10_RXP); also elsewhere on the board
PCH_x4_1_PCIe_Rx3-: UPCH1.N18 (PCIE4_RXN/USB3.1G1_10_RXN); also elsewhere on the board
PCH_x4_1_PCIe_Tx0+: UPCH1.B17 (PCIE1_TXP/USB3.1G1_7_TXP); also elsewhere on the board
PCH_x4_1_PCIe_Tx0-: UPCH1.A17 (PCIE1_TXN/USB3.1G1_7_TXN); also elsewhere on the board
PCH_x4_1_PCIe_Tx1+: UPCH1.C18 (PCIE2_TXP/USB3.1G1_8_TXP); also elsewhere on the board
PCH_x4_1_PCIe_Tx1-: UPCH1.B18 (PCIE2_TXN/USB3.1G1_8_TXN); also elsewhere on the board
PCH_x4_1_PCIe_Tx2+: UPCH1.C19 (PCIE3_TXP/USB3.1G1_9_TXP); also elsewhere on the board
PCH_x4_1_PCIe_Tx2-: UPCH1.B19 (PCIE3_TXN/USB3.1G1_9_TXN); also elsewhere on the board
PCH_x4_1_PCIe_Tx3+: UPCH1.C20 (PCIE4_TXP/USB3.1G1_10_TXP); also elsewhere on the board
PCH_x4_1_PCIe_Tx3-: UPCH1.D20 (PCIE4_TXN/USB3.1G1_10_TXN); also elsewhere on the board
PCH_x4_1_Refclk+: UPCH1.AB3 (CLKOUT_PCIE_P5); also elsewhere on the board
PCH_x4_1_Refclk-: UPCH1.AB2 (CLKOUT_PCIE_N5); also elsewhere on the board
PCH_x4_4_CLKREQ#: UPCH1.BA30 (GPP_B9/SRCCLKREQ4#); also elsewhere on the board
PCH_x4_4_PCIe_Rx0+: UPCH1.C38 (PCIE13_TXP/SATA0B_TXP); also elsewhere on the board
PCH_x4_4_PCIe_Rx0-: UPCH1.B38 (PCIE13_TXN/SATA0B_TXN); also elsewhere on the board
PCH_x4_4_PCIe_Rx1+: UPCH1.D39 (PCIE14_TXP/SATA1B_TXP); also elsewhere on the board
PCH_x4_4_PCIe_Rx1-: UPCH1.C39 (PCIE14_TXN/SATA1B_TXN); also elsewhere on the board
PCH_x4_4_PCIe_Rx2+: UPCH1.C40 (PCIE15_TXP/SATA2_TXP); also elsewhere on the board
PCH_x4_4_PCIe_Rx2-: UPCH1.B40 (PCIE15_TXN/SATA2_TXN); also elsewhere on the board
PCH_x4_4_PCIe_Rx3+: UPCH1.C41 (PCIE16_TXP/SATA3_TXP); also elsewhere on the board
PCH_x4_4_PCIe_Rx3-: UPCH1.B41 (PCIE16_TXN/SATA3_TXN); also elsewhere on the board
PCH_x4_4_PCIe_Tx0+: UPCH1.C46 (PCIE13_RXP/SATA0B_RXP); also elsewhere on the board
PCH_x4_4_PCIe_Tx0-: UPCH1.C45 (PCIE13_RXN/SATA0B_RXN); also elsewhere on the board
PCH_x4_4_PCIe_Tx1+: UPCH1.C47 (PCIE14_RXP/SATA1B_RXP); also elsewhere on the board
PCH_x4_4_PCIe_Tx1-: UPCH1.D46 (PCIE14_RXN/SATA1B_RXN); also elsewhere on the board
PCH_x4_4_PCIe_Tx2+: UPCH1.E45 (PCIE15_RXP/SATA2_RXP); also elsewhere on the board
PCH_x4_4_PCIe_Tx2-: UPCH1.F44 (PCIE15_RXN/SATA2_RXN); also elsewhere on the board
PCH_x4_4_PCIe_Tx3+: UPCH1.M40 (PCIE16_RXP/SATA3_RXP); also elsewhere on the board
PCH_x4_4_PCIe_Tx3-: UPCH1.L41 (PCIE16_RXN/SATA3_RXN); also elsewhere on the board
PCH_x4_4_Refclk+: UPCH1.AC3 (CLKOUT_PCIE_P4); also elsewhere on the board
PCH_x4_4_Refclk-: UPCH1.AC2 (CLKOUT_PCIE_N4); also elsewhere on the board
PCH_x4_5_CLKREQ#: UPCH1.BB30 (GPP_B8/SRCCLKREQ3#); also elsewhere on the board
PCH_x4_5_PCIe_Rx0+: UPCH1.K44 (PCIE17_RXP/SATA4_RXP); also elsewhere on the board
PCH_x4_5_PCIe_Rx0-: UPCH1.K43 (PCIE17_RXN/SATA4_RXN); also elsewhere on the board
PCH_x4_5_PCIe_Rx1+: UPCH1.R40 (PCIE18_RXP/SATA5_RXP); also elsewhere on the board
PCH_x4_5_PCIe_Rx1-: UPCH1.P41 (PCIE18_RXN/SATA5_RXN); also elsewhere on the board
PCH_x4_5_PCIe_Rx2+: UPCH1.N42 (PCIE19_RXP/SATA6_RXP); also elsewhere on the board
PCH_x4_5_PCIe_Rx2-: UPCH1.M44 (PCIE19_RXN/SATA6_RXN); also elsewhere on the board
PCH_x4_5_PCIe_Rx3+: UPCH1.R37 (PCIE20_RXP/SATA7_RXP); also elsewhere on the board
PCH_x4_5_PCIe_Rx3-: UPCH1.R35 (PCIE20_RXN/SATA7_RXN); also elsewhere on the board
PCH_x4_5_PCIe_Tx0+: UPCH1.B42 (PCIE17_TXP/SATA4_TXP); also elsewhere on the board
PCH_x4_5_PCIe_Tx0-: UPCH1.A42 (PCIE17_TXN/SATA4_TXN); also elsewhere on the board
PCH_x4_5_PCIe_Tx1+: UPCH1.D42 (PCIE18_TXP/SATA5_TXP); also elsewhere on the board
PCH_x4_5_PCIe_Tx1-: UPCH1.C42 (PCIE18_TXN/SATA5_TXN); also elsewhere on the board
PCH_x4_5_PCIe_Tx2+: UPCH1.D43 (PCIE19_TXP/SATA6_TXP); also elsewhere on the board
PCH_x4_5_PCIe_Tx2-: UPCH1.C44 (PCIE19_TXN/SATA6_TXN); also elsewhere on the board
PCH_x4_5_PCIe_Tx3+: UPCH1.B44 (PCIE20_TXP/SATA7_TXP); also elsewhere on the board
PCH_x4_5_PCIe_Tx3-: UPCH1.A44 (PCIE20_TXN/SATA7_TXN); also elsewhere on the board
PCH_x4_5_Refclk+: UPCH1.AE7 (CLKOUT_PCIE_P3); also elsewhere on the board
PCH_x4_5_Refclk-: UPCH1.AE6 (CLKOUT_PCIE_N3); also elsewhere on the board
PCH_x4_6_CLKREQ#: UPCH1.AR32 (GPP_B7/SRCCLKREQ2#); also elsewhere on the board
PCH_x4_6_PCIe_Rx0+: UPCH1.R44 (PCIE21_RXP); also elsewhere on the board
PCH_x4_6_PCIe_Rx0-: UPCH1.T43 (PCIE21_RXN); also elsewhere on the board
PCH_x4_6_PCIe_Rx1+: UPCH1.U41 (PCIE22_RXP); also elsewhere on the board
PCH_x4_6_PCIe_Rx1-: UPCH1.U40 (PCIE22_RXN); also elsewhere on the board
PCH_x4_6_PCIe_Rx2+: UPCH1.W44 (PCIE23_RXP); also elsewhere on the board
PCH_x4_6_PCIe_Rx2-: UPCH1.W43 (PCIE23_RXN); also elsewhere on the board
PCH_x4_6_PCIe_Rx3+: UPCH1.Y41 (PCIE24_RXP); also elsewhere on the board
PCH_x4_6_PCIe_Rx3-: UPCH1.Y40 (PCIE24_RXN); also elsewhere on the board
PCH_x4_6_PCIe_Tx0+: UPCH1.F46 (PCIE21_TXP); also elsewhere on the board
PCH_x4_6_PCIe_Tx0-: UPCH1.G47 (PCIE21_TXN); also elsewhere on the board
PCH_x4_6_PCIe_Tx1+: UPCH1.H48 (PCIE22_TXP); also elsewhere on the board
PCH_x4_6_PCIe_Tx1-: UPCH1.H47 (PCIE22_TXN); also elsewhere on the board
PCH_x4_6_PCIe_Tx2+: UPCH1.G48 (PCIE23_TXP); also elsewhere on the board
PCH_x4_6_PCIe_Tx2-: UPCH1.G49 (PCIE23_TXN); also elsewhere on the board
PCH_x4_6_PCIe_Tx3+: UPCH1.G45 (PCIE24_TXP); also elsewhere on the board
PCH_x4_6_PCIe_Tx3-: UPCH1.G46 (PCIE24_TXN); also elsewhere on the board
PCH_x4_6_Refclk+: UPCH1.AE15 (CLKOUT_PCIE_P2); also elsewhere on the board
PCH_x4_6_Refclk-: UPCH1.AE14 (CLKOUT_PCIE_N2); also elsewhere on the board
PCIe_CPU_CLKREQ#: UPCH1.BF31 (GPP_B5/SRCCLKREQ0#); also elsewhere on the board
PCIe_CPU_Refclk+: UPCH1.AJ7 (CLKOUT_PCIE_P0); also elsewhere on the board
PCIe_CPU_Refclk-: UPCH1.AJ6 (CLKOUT_PCIE_N0); also elsewhere on the board
PECI_PCH: R41.2, UPCH1.AF2 (PECI); also elsewhere on the board
PLTRST_CPU#: UPCH1.AG5 (PLTRST_CPU#); also elsewhere on the board
PM_DOWN_PCH: UPCH1.AE2 (PM_DOWN); also elsewhere on the board
PM_SYNC_PCH: UPCH1.AF3 (PM_SYNC); also elsewhere on the board
SSD0_CLKREQ#: UPCH1.BE31 (GPP_B6/SRCCLKREQ1#); also elsewhere on the board
SSD0_PCIe_Rx1+: UPCH1.F39 (PCIE11_RXP/SATA0A_RXP); also elsewhere on the board
SSD0_PCIe_Rx1-: UPCH1.G38 (PCIE11_RXN/SATA0A_RXN); also elsewhere on the board
SSD0_PCIe_Rx2+: UPCH1.J37 (PCIE10_RXP); also elsewhere on the board
SSD0_PCIe_Rx2-: UPCH1.K37 (PCIE10_RXN); also elsewhere on the board
SSD0_PCIe_Rx3+: UPCH1.F36 (PCIE9_RXP); also elsewhere on the board
SSD0_PCIe_Rx3-: UPCH1.G36 (PCIE9_RXN); also elsewhere on the board
SSD0_PCIe_Tx1+: UPCH1.C36 (PCIE11_TXP/SATA0A_TXP); also elsewhere on the board
SSD0_PCIe_Tx1-: UPCH1.B36 (PCIE11_TXN/SATA0A_TXN); also elsewhere on the board
SSD0_PCIe_Tx2+: UPCH1.B35 (PCIE10_TXP); also elsewhere on the board
SSD0_PCIe_Tx2-: UPCH1.C35 (PCIE10_TXN); also elsewhere on the board
SSD0_PCIe_Tx3+: UPCH1.D34 (PCIE9_TXP); also elsewhere on the board
SSD0_PCIe_Tx3-: UPCH1.C34 (PCIE9_TXN); also elsewhere on the board
SSD0_Refclk+: UPCH1.AH10 (CLKOUT_PCIE_P1); also elsewhere on the board
SSD0_Refclk-: UPCH1.AH9 (CLKOUT_PCIE_N1); also elsewhere on the board
SSD0_SATA/PCIe_Rx0+: UPCH1.J41 (PCIE12_RXP/SATA1A_RXP); also elsewhere on the board
SSD0_SATA/PCIe_Rx0-: UPCH1.H42 (PCIE12_RXN/SATA1A_RXN); also elsewhere on the board
SSD0_SATA/PCIe_Tx0+: UPCH1.E37 (PCIE12_TXP/SATA1A_TXP); also elsewhere on the board
SSD0_SATA/PCIe_Tx0-: UPCH1.D38 (PCIE12_TXN/SATA1A_TXN); also elsewhere on the board
S_DMI_CRx_PTx_0+: UPCH1.B33 (DMI0_TXP); also elsewhere on the board
S_DMI_CRx_PTx_0-: UPCH1.C33 (DMI0_TXN); also elsewhere on the board
S_DMI_CRx_PTx_1+: UPCH1.B32 (DMI1_TXP); also elsewhere on the board
S_DMI_CRx_PTx_1-: UPCH1.C32 (DMI1_TXN); also elsewhere on the board
S_DMI_CRx_PTx_2+: UPCH1.B31 (DMI2_TXP); also elsewhere on the board
S_DMI_CRx_PTx_2-: UPCH1.C31 (DMI2_TXN); also elsewhere on the board
S_DMI_CRx_PTx_3+: UPCH1.B29 (DMI3_TXP); also elsewhere on the board
S_DMI_CRx_PTx_3-: UPCH1.C29 (DMI3_TXN); also elsewhere on the board
S_DMI_CRx_PTx_4+: UPCH1.D29 (DMI4_TXP); also elsewhere on the board
S_DMI_CRx_PTx_4-: UPCH1.E28 (DMI4_TXN); also elsewhere on the board
S_DMI_CRx_PTx_5+: UPCH1.B27 (DMI5_TXP); also elsewhere on the board
S_DMI_CRx_PTx_5-: UPCH1.C27 (DMI5_TXN); also elsewhere on the board
S_DMI_CRx_PTx_6+: UPCH1.C26 (DMI6_TXP); also elsewhere on the board
S_DMI_CRx_PTx_6-: UPCH1.B26 (DMI6_TXN); also elsewhere on the board
S_DMI_CRx_PTx_7+: UPCH1.A25 (DMI7_TXP); also elsewhere on the board
S_DMI_CRx_PTx_7-: UPCH1.B25 (DMI7_TXN); also elsewhere on the board
S_DMI_CTx_PRx_0+: UPCH1.J35 (DMI0_RXP); also elsewhere on the board
S_DMI_CTx_PRx_0-: UPCH1.K34 (DMI0_RXN); also elsewhere on the board
S_DMI_CTx_PRx_1+: UPCH1.F34 (DMI1_RXP); also elsewhere on the board
S_DMI_CTx_PRx_1-: UPCH1.G33 (DMI1_RXN); also elsewhere on the board
S_DMI_CTx_PRx_2+: UPCH1.J32 (DMI2_RXP); also elsewhere on the board
S_DMI_CTx_PRx_2-: UPCH1.K32 (DMI2_RXN); also elsewhere on the board
S_DMI_CTx_PRx_3+: UPCH1.F30 (DMI3_RXP); also elsewhere on the board
S_DMI_CTx_PRx_3-: UPCH1.G30 (DMI3_RXN); also elsewhere on the board
S_DMI_CTx_PRx_4+: UPCH1.K29 (DMI4_RXP); also elsewhere on the board
S_DMI_CTx_PRx_4-: UPCH1.M29 (DMI4_RXN); also elsewhere on the board
S_DMI_CTx_PRx_5+: UPCH1.L26 (DMI5_RXP); also elsewhere on the board
S_DMI_CTx_PRx_5-: UPCH1.M26 (DMI5_RXN); also elsewhere on the board
S_DMI_CTx_PRx_6+: UPCH1.F26 (DMI6_RXP); also elsewhere on the board
S_DMI_CTx_PRx_6-: UPCH1.G26 (DMI6_RXN); also elsewhere on the board
S_DMI_CTx_PRx_7+: UPCH1.P24 (DMI7_RXP); also elsewhere on the board
S_DMI_CTx_PRx_7-: UPCH1.R24 (DMI7_RXN); also elsewhere on the board
THERMTRIP#: R38.2; also elsewhere on the board
eDP_BLEN: UPCH1.AV46 (GPP_F20/EDP_BKLTEN)
eDP_PWM: UPCH1.AU48 (GPP_F21/EDP_BKLTCTL); also elsewhere on the board
eDP_VDDEN: UPCH1.AV44 (GPP_F19/EDP_VDDEN)

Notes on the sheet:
subtract 5 for PCIe lane number (first 6 lanes are the USB3.1G2 ports + index starts at 0 vs 1)
Keep CLKREQ# and Refclk+/- paired!
Z390 pls (or Q370 but idk how to handle AMT)
PCIe controller 1 (L1-4): ? PCIe controller 2 (L5-8): ? PCIe controller 3 (L9-12): NVMe 0 with lane reversal for SATA on first lane x2 no SATA on H310, x4 with SATA on all other chipsets PCIe controller 4 (L13-16): ? PCIe controller 5 (L17-20): ? PCIe controller 6 (L21-24): ?
PCIe controller 4 (L13-16): Z390/Q370/H370/C246/CM246: 4x SATA + PCIe x4 QM370/HM370: 2x SATA L13/14 + PCIe x4 B360/H310: 4x SATA (GbE supported) C242: 4x SATA -Used for PCIe x4 or 4x SATA adapter
PCIe controller 5 (L17-20): Z390/Q370/QM370/HM370: 2x SATA L17/18 + PCIe x4 H370: 2x SATA L17/18 + PCIe x2 L19/20 B360/C242: 2x SATA L17/18 C246/CM246: 4x SATA + PCIe x4 H310: nothing -Used for PCIe x4 or 4x SATA adapter
PCIe controller 3 (L9-12): H310: PCIe x2 L11/12 All other chipsets: 2x SATA L11/12 + PCIe x4 -Used for NVMe 0 with lane reversal for SATA on first lane
PCIe controller 6 (L21-24): H310: nothing All other chipsets: PCIe x4 -Used for PCIe x4
PCIe controller 1 (L1-4): Z390/Q370/C246/CM246: 4x USB3 + PCIe x4 H370: 2x USB3 L1/2 + PCIe x2 L3/4 C242: PCIe x2 L1/2 HM370: 2x USB3 L1/2 QM370: 4x USB3 B360/H310: nothing -Used for PCIe x4 or 4x USB3 adapter
PCIe controller 2 (L5-8): HM370/C242: nothing All other chipsets: PCIe x4 -Used for: L5: GbE i219 L6: 2.5Gb? L7: A/E-key? L8: A/E-key L2/miniPCIe?

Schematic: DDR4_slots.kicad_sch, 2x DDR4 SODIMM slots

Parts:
JSODIMM1, JSODIMM2: DDR4-sodimm; DDR4-sodimm-std
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

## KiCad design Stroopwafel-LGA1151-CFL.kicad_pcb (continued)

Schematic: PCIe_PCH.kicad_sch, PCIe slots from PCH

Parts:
C69, C70, C71, C72, C73, C74, C75, C76, C77, C78, C79, C80, C81, C82, C83, C84, C85, C86, C87, C88, C89, C90, C91, C92, C93, C94, C95, C96, C97, C98, C99, C100, C101, C102, C103, C104, C105, C106, C107, C108: 0.22uF; C_0402_1005Metric
J6: Bus_M.2_Socket_M; m-key
J7: PCIe_x4_PCH_6; PCIe_x4_tht_open
J10: PCIe_x4_PCH_5; PCIe_x4_tht_open
J11: PCIe_x4_PCH_4; PCIe_x4_tht_open
J12: PCIe_x4_PCH_1; PCIe_x4_tht_open

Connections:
/PCIe_PCH/PCH_x4_1_PCIe_C_Tx0+: C101.2, J12.B14 (PETp0)
/PCIe_PCH/PCH_x4_1_PCIe_C_Tx0-: C102.2, J12.B15 (PETn0)
/PCIe_PCH/PCH_x4_1_PCIe_C_Tx1+: C103.2, J12.B19 (PETp1)
/PCIe_PCH/PCH_x4_1_PCIe_C_Tx1-: C104.2, J12.B20 (PETn1)
/PCIe_PCH/PCH_x4_1_PCIe_C_Tx2+: C105.2, J12.B23 (PETp2)
/PCIe_PCH/PCH_x4_1_PCIe_C_Tx2-: C106.2, J12.B24 (PETn2)
/PCIe_PCH/PCH_x4_1_PCIe_C_Tx3+: C107.2, J12.B27 (PETp3)
/PCIe_PCH/PCH_x4_1_PCIe_C_Tx3-: C108.2, J12.B28 (PETn3)
/PCIe_PCH/PCH_x4_4_PCIe_C_Tx0+: C93.2, J11.B14 (PETp0)
/PCIe_PCH/PCH_x4_4_PCIe_C_Tx0-: C94.2, J11.B15 (PETn0)
/PCIe_PCH/PCH_x4_4_PCIe_C_Tx1+: C95.2, J11.B19 (PETp1)
/PCIe_PCH/PCH_x4_4_PCIe_C_Tx1-: C96.2, J11.B20 (PETn1)
/PCIe_PCH/PCH_x4_4_PCIe_C_Tx2+: C97.2, J11.B23 (PETp2)
/PCIe_PCH/PCH_x4_4_PCIe_C_Tx2-: C98.2, J11.B24 (PETn2)
/PCIe_PCH/PCH_x4_4_PCIe_C_Tx3+: C99.2, J11.B27 (PETp3)
/PCIe_PCH/PCH_x4_4_PCIe_C_Tx3-: C100.2, J11.B28 (PETn3)
/PCIe_PCH/PCH_x4_5_PCIe_C_Tx0+: C85.2, J10.B14 (PETp0)
/PCIe_PCH/PCH_x4_5_PCIe_C_Tx0-: C86.2, J10.B15 (PETn0)
/PCIe_PCH/PCH_x4_5_PCIe_C_Tx1+: C87.2, J10.B19 (PETp1)
/PCIe_PCH/PCH_x4_5_PCIe_C_Tx1-: C88.2, J10.B20 (PETn1)
/PCIe_PCH/PCH_x4_5_PCIe_C_Tx2+: C89.2, J10.B23 (PETp2)
/PCIe_PCH/PCH_x4_5_PCIe_C_Tx2-: C90.2, J10.B24 (PETn2)
/PCIe_PCH/PCH_x4_5_PCIe_C_Tx3+: C91.2, J10.B27 (PETp3)
/PCIe_PCH/PCH_x4_5_PCIe_C_Tx3-: C92.2, J10.B28 (PETn3)
/PCIe_PCH/PCH_x4_6_PCIe_C_Tx0+: C77.2, J7.B14 (PETp0)
/PCIe_PCH/PCH_x4_6_PCIe_C_Tx0-: C78.2, J7.B15 (PETn0)
/PCIe_PCH/PCH_x4_6_PCIe_C_Tx1+: C79.2, J7.B19 (PETp1)
/PCIe_PCH/PCH_x4_6_PCIe_C_Tx1-: C80.2, J7.B20 (PETn1)
/PCIe_PCH/PCH_x4_6_PCIe_C_Tx2+: C81.2, J7.B23 (PETp2)
/PCIe_PCH/PCH_x4_6_PCIe_C_Tx2-: C82.2, J7.B24 (PETn2)
/PCIe_PCH/PCH_x4_6_PCIe_C_Tx3+: C83.2, J7.B27 (PETp3)
/PCIe_PCH/PCH_x4_6_PCIe_C_Tx3-: C84.2, J7.B28 (PETn3)
/PCIe_PCH/SSD0_PCIe_C_Tx1+: C71.2, J6.37 (PETp1)
/PCIe_PCH/SSD0_PCIe_C_Tx1-: C72.2, J6.35 (PETn1)
/PCIe_PCH/SSD0_PCIe_C_Tx2+: C73.2, J6.25 (PETp2)
/PCIe_PCH/SSD0_PCIe_C_Tx2-: C74.2, J6.23 (PETn2)
/PCIe_PCH/SSD0_PCIe_C_Tx3+: C75.2, J6.13 (PETp3)
/PCIe_PCH/SSD0_PCIe_C_Tx3-: C76.2, J6.11 (PETn3)
/PCIe_PCH/SSD0_SATA/PCIe_C_Tx0+: C69.2, J6.49 (PETp0/SATA-A+)
/PCIe_PCH/SSD0_SATA/PCIe_C_Tx0-: C70.2, J6.47 (PETn0/SATA-A-)
GND: J6.1 (GND), J6.3 (GND), J6.9 (GND), J6.15 (GND), J6.21 (GND), J6.27 (GND), J6.33 (GND), J6.39 (GND), J6.45 (GND), J6.51 (GND), J6.57 (GND), J6.71 (GND), J6.73 (GND), J6.75 (GND), J7.A1 (~PRSNT1), J10.A1 (~PRSNT1), J11.A1 (~PRSNT1), J12.A1 (~PRSNT1); also elsewhere on the board
unnamed: J7.A4 (GND), J7.A12 (GND), J7.A15 (GND), J7.A18 (GND), J7.A20 (GND), J7.A23 (GND), J7.A24 (GND), J7.A27 (GND), J7.A28 (GND), J7.A31 (GND)
unnamed: J7.B4 (GND), J7.B7 (GND), J7.B13 (GND), J7.B16 (GND), J7.B18 (GND), J7.B21 (GND), J7.B22 (GND), J7.B25 (GND), J7.B26 (GND), J7.B29 (GND), J7.B32 (GND)
unnamed: J10.A4 (GND), J10.A12 (GND), J10.A15 (GND), J10.A18 (GND), J10.A20 (GND), J10.A23 (GND), J10.A24 (GND), J10.A27 (GND), J10.A28 (GND), J10.A31 (GND)
unnamed: J10.B4 (GND), J10.B7 (GND), J10.B13 (GND), J10.B16 (GND), J10.B18 (GND), J10.B21 (GND), J10.B22 (GND), J10.B25 (GND), J10.B26 (GND), J10.B29 (GND), J10.B32 (GND)
unnamed: J11.A4 (GND), J11.A12 (GND), J11.A15 (GND), J11.A18 (GND), J11.A20 (GND), J11.A23 (GND), J11.A24 (GND), J11.A27 (GND), J11.A28 (GND), J11.A31 (GND)
unnamed: J11.B4 (GND), J11.B7 (GND), J11.B13 (GND), J11.B16 (GND), J11.B18 (GND), J11.B21 (GND), J11.B22 (GND), J11.B25 (GND), J11.B26 (GND), J11.B29 (GND), J11.B32 (GND)
unnamed: J12.A4 (GND), J12.A12 (GND), J12.A15 (GND), J12.A18 (GND), J12.A20 (GND), J12.A23 (GND), J12.A24 (GND), J12.A27 (GND), J12.A28 (GND), J12.A31 (GND)
unnamed: J12.B4 (GND), J12.B7 (GND), J12.B13 (GND), J12.B16 (GND), J12.B18 (GND), J12.B21 (GND), J12.B22 (GND), J12.B25 (GND), J12.B26 (GND), J12.B29 (GND), J12.B32 (GND)
PCH_x4_1_CLKREQ#: J12.B17 (~PRSNT2), J12.B31 (~PRSNT2); also elsewhere on the board
PCH_x4_1_PCIe_Rx0+: J12.A16 (PERp0); also elsewhere on the board
PCH_x4_1_PCIe_Rx0-: J12.A17 (PERn0); also elsewhere on the board
PCH_x4_1_PCIe_Rx1+: J12.A21 (PERp1); also elsewhere on the board
PCH_x4_1_PCIe_Rx1-: J12.A22 (PERn1); also elsewhere on the board
PCH_x4_1_PCIe_Rx2+: J12.A25 (PERp2); also elsewhere on the board
PCH_x4_1_PCIe_Rx2-: J12.A26 (PERn2); also elsewhere on the board
PCH_x4_1_PCIe_Rx3+: J12.A29 (PERp3); also elsewhere on the board
PCH_x4_1_PCIe_Rx3-: J12.A30 (PERn3); also elsewhere on the board
PCH_x4_1_PCIe_Tx0+: C101.1; also elsewhere on the board
PCH_x4_1_PCIe_Tx0-: C102.1; also elsewhere on the board
PCH_x4_1_PCIe_Tx1+: C103.1; also elsewhere on the board
PCH_x4_1_PCIe_Tx1-: C104.1; also elsewhere on the board
PCH_x4_1_PCIe_Tx2+: C105.1; also elsewhere on the board
PCH_x4_1_PCIe_Tx2-: C106.1; also elsewhere on the board
PCH_x4_1_PCIe_Tx3+: C107.1; also elsewhere on the board
PCH_x4_1_PCIe_Tx3-: C108.1; also elsewhere on the board
PCH_x4_1_Refclk+: J12.A13 (REFCLK+); also elsewhere on the board
PCH_x4_1_Refclk-: J12.A14 (REFCLK-); also elsewhere on the board
PCH_x4_4_CLKREQ#: J11.B17 (~PRSNT2), J11.B31 (~PRSNT2); also elsewhere on the board
PCH_x4_4_PCIe_Rx0+: J11.A16 (PERp0); also elsewhere on the board
PCH_x4_4_PCIe_Rx0-: J11.A17 (PERn0); also elsewhere on the board
PCH_x4_4_PCIe_Rx1+: J11.A21 (PERp1); also elsewhere on the board
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

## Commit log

2025-09-05 Added work in progress CPU symbol and socket footprint
    [CPU_Memory.kicad_sch, Stroopwafel-LGA1151-CFL.kicad_pcb, Stroopwafel-LGA1151-CFL.kicad_sch]
2025-09-06 Completed DDR4 channel 0 symbol
    [CPU_Memory.kicad_sch]
2025-09-06 added WIP symbol for DDR4 channel 1
    [CPU_Memory.kicad_sch]
2025-09-06 Completed DDR4 channel 1 symbol
    [CPU_Memory.kicad_sch]
2025-09-06 rotated socket
    [CPU_Memory.kicad_sch, Stroopwafel-LGA1151-CFL.kicad_pcb]
2025-09-06 Added PEG/DMI symbol
    [CPU_Memory.kicad_sch, CPU_PEG_DMI.kicad_sch, Stroopwafel-LGA1151-CFL.kicad_sch]
2025-09-06 Added CPU DDI symbol
    [CPU_Display.kicad_sch, CPU_Memory.kicad_sch, Stroopwafel-LGA1151-CFL.kicad_sch]
2025-09-06 Added CPU clock/cfg/vid/jtag symbol
    [CPU_CLK_CFG_VID_JTAG.kicad_sch, CPU_Memory.kicad_sch, CPU_PEG_DMI.kicad_sch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]
2025-09-06 Added CPU GND and Core VCC symbols
    [CPU_Display.kicad_sch, CPU_GND.kicad_sch, CPU_Memory.kicad_sch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]
2025-09-06 Added iGPU VCC symbol
    [CPU_CLK_CFG_VID_JTAG.kicad_sch, CPU_Display.kicad_sch, CPU_GND.kicad_sch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]
2025-09-06 Added CPU Misc VCC symbol
    [CPU_CLK_CFG_VID_JTAG.kicad_sch, CPU_Display.kicad_sch, CPU_GND.kicad_sch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]
2025-09-06 Added CPU Misc & RSVD symbol
    [CPU_CLK_CFG_VID_JTAG.kicad_sch, CPU_Display.kicad_sch, CPU_GND.kicad_sch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]
2025-09-06 Added the last 2 CPU Ground symbols, CPU symbol set complete
    [CPU_CLK_CFG_VID_JTAG.kicad_sch, CPU_Display.kicad_sch, CPU_GND.kicad_sch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]
2025-09-06 Connected CPU ground
    [CPU_CLK_CFG_VID_JTAG.kicad_sch, CPU_Display.kicad_sch, CPU_GND.kicad_sch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]
2025-09-06 Added first PCH symbol and footprint
    THANKS @mothenjoyer69 so much for extracting and converting the PCH footprint from a laptop boardview ❤️
    [CPU_CLK_CFG_VID_JTAG.kicad_sch, CPU_Display.kicad_sch, CPU_GND.kicad_sch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]
2025-09-07 Added all the PCH symbols
    that took 1.5 days straight lol
    [CPU_CLK_CFG_VID_JTAG.kicad_sch, CPU_Display.kicad_sch, CPU_GND.kicad_sch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]
2025-09-09 Fixed some PCH pin names
    [CPU_GND.kicad_sch, CPU_Memory.kicad_sch, PCH_temp.kicad_sch]
2025-09-09 replaced PCH symbol set with modified more sane version
    seriously what was intel thinking when laying out half of those symbols, i can't make sense of their choices
    if you want the original version take it from the commit before this one I guess
    [PCH_temp.kicad_sch, Stroopwafel-LGA1151-CFL.kicad_pcb]
2025-09-09 Connected DMI for fun (with lane reversal)
    [CPU_PEG_DMI.kicad_sch, PCH_temp.kicad_sch, Stroopwafel-LGA1151-CFL.kicad_pcb]
2025-09-09 Moved PCH symbols to their own pages
    [PCH_Highspeed_Clock_LPC_eSPI.kicad_sch, PCH_Lowspeed_SPI_HDA_GPIO.kicad_sch, PCH_VCC_GND.kicad_sch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]
2025-09-09 Titled PCH pages
    [PCH_Highspeed_Clock_LPC_eSPI.kicad_sch, PCH_Lowspeed_SPI_HDA_GPIO.kicad_sch, PCH_VCC_GND.kicad_sch]
2025-09-09 Updated pcb file for new schematic layout
    [CPU_PEG_DMI.kicad_sch, PCH_Highspeed_Clock_LPC_eSPI.kicad_sch, PCH_Lowspeed_SPI_HDA_GPIO.kicad_sch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]
2025-09-09 Fixed some incorrect pin names
    somehow it was wrong on Intel's symbol on the reference schematic, the datasheet has it correct. I wonder how many more pins are like this.....
    [PCH_Highspeed_Clock_LPC_eSPI.kicad_sch, PCH_Lowspeed_SPI_HDA_GPIO.kicad_sch, PCH_VCC_GND.kicad_sch]
2025-10-09 Added sodimm memory slots and mostly hooked them up on the schematic
    [CPU_Memory.kicad_sch, DDR4_slots.kicad_sch, Stroopwafel-LGA1151-CFL.kicad_pcb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]
2025-10-09 Added pretty colors
    pretty fun to do
    [CPU_Memory.kicad_sch, Stroopwafel-LGA1151-CFL.kicad_pcb]
2025-10-09 Added PCIe x16 slot
    [CPU_PEG_DMI.kicad_sch, Stroopwafel-LGA1151-CFL.kicad_pcb]
2025-10-12 Added pcie slot and cpu clocks
    [CPU_CLK_CFG_VID_JTAG.kicad_sch, CPU_PEG_DMI.kicad_sch, PCH_Highspeed_Clock_LPC_eSPI.kicad_sch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]
2025-10-13 Some DP and power work
    [CPU_Display.kicad_sch, CPU_VCC.kicad_sch, Display_ports.kicad_sch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]
2025-10-13 More DP
    [CPU_Display.kicad_sch, Display_ports.kicad_sch, PCH_Lowspeed_SPI_HDA_GPIO.kicad_sch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]
2025-10-15 Added note about Intel schematic symbol corrections
    Seriously who made those, awful layout + didn't even fully match the datasheet.
    There might be more to fix, will see as I go.
2025-10-15 Added PCH SKU IO table screenshot from datasheet to schematic
    and a note about display audio
    [Display_ports.kicad_sch, PCH_Highspeed_Clock_LPC_eSPI.kicad_sch, PCH_Lowspeed_SPI_HDA_GPIO.kicad_sch]
2025-10-18 Added DP_A DP++ HDMI dongle detection circuit
    [CPU_Memory.kicad_sch, DDR4_slots.kicad_sch, Display_ports.kicad_sch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]
2025-10-18 added DP_A DDC pullups
    [Display_ports.kicad_sch]
2025-10-22 partially added eDP + rearranged other display stuff
    [CPU_CLK_CFG_VID_JTAG.kicad_sch, CPU_Display.kicad_sch, CPU_PEG_DMI.kicad_sch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]
2025-10-23 Added LGA1151 socket bracket holes
    stolen from another lga1151 footprint that has wrong pin numbers....
    [CPU_CLK_CFG_VID_JTAG.kicad_sch, CPU_Display.kicad_sch, CPU_GND.kicad_sch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]
2025-10-24 Added CPU CFG resistors
    [CPU_CLK_CFG_VID_JTAG.kicad_sch, CPU_Display.kicad_sch, CPU_GND.kicad_sch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]
2025-10-26 Added PCH PCIe rootport/bifurcation notes
    [CPU_Display.kicad_sch, CPU_Misc.kicad_sch, PCH_Highspeed_Clock_LPC_eSPI.kicad_sch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]
2025-10-26 Fixed 2 pins that somehow disappeared from schematic
    i blame my kicad libraries being weird lol
    [PCH_Highspeed_Clock_LPC_eSPI.kicad_sch, PCH_Lowspeed_SPI_HDA_GPIO.kicad_sch, PCH_VCC_GND.kicad_sch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]
2025-10-28 Made a cool table of contents on the root schematic page
    [Stroopwafel-LGA1151-CFL.kicad_sch]
2025-10-28 moved root page stuff around a bit
    [Stroopwafel-LGA1151-CFL.kicad_sch]
2025-10-28 Fixed entire schematic being broken
    somehow every symbol with index 1 broke and updating the pcb stopped working. how does that even happen. oh well it's fixed now
    [CPU_CLK_CFG_VID_JTAG.kicad_sch, CPU_Display.kicad_sch, CPU_GND.kicad_sch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]
2025-11-03 nooo they be stealin my stroopwafel
    [CPU_GND.kicad_sch, CPU_Memory.kicad_sch, CPU_VCC.kicad_sch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]
2025-11-13 implemented some misc cpu signals
    [CPU_CLK_CFG_VID_JTAG.kicad_sch, CPU_Display.kicad_sch, EC.kicad_sch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]
2026-01-03 idek what i changed anymore but there's a bunch of new stuff lol
    iirc i did some more misc cpu pins and a bunch of pch pcie stuff
    [CPU_CLK_CFG_VID_JTAG.kicad_sch, CPU_VCC.kicad_sch, EC.kicad_sch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]
2026-01-04 more pcie notes
    [PCH_Highspeed_Clock_LPC_eSPI.kicad_sch]
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2026-05-30 Added interconnect between CPU and PCH boards and added ATX board outline
    [Blockdiagram.kicad_sch, CPU_PEG_DMI.kicad_sch, CPU_Power.kicad_sch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]
2026-05-31 Added more PCIe slots and mounting holes
    [Blockdiagram.kicad_sch, PCH_Highspeed_Clock_LPC_eSPI.kicad_sch, PCIe_PCH.kicad_sch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]
